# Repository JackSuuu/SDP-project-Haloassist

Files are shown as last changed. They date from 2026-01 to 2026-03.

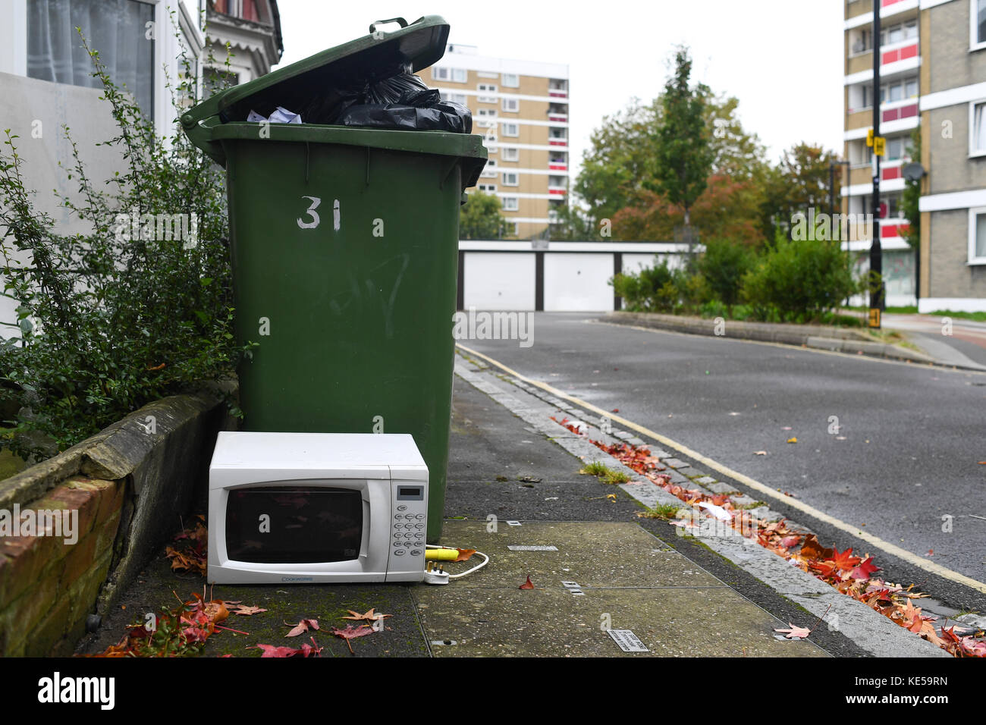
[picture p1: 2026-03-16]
perception/test_images/microwave_far.jpg

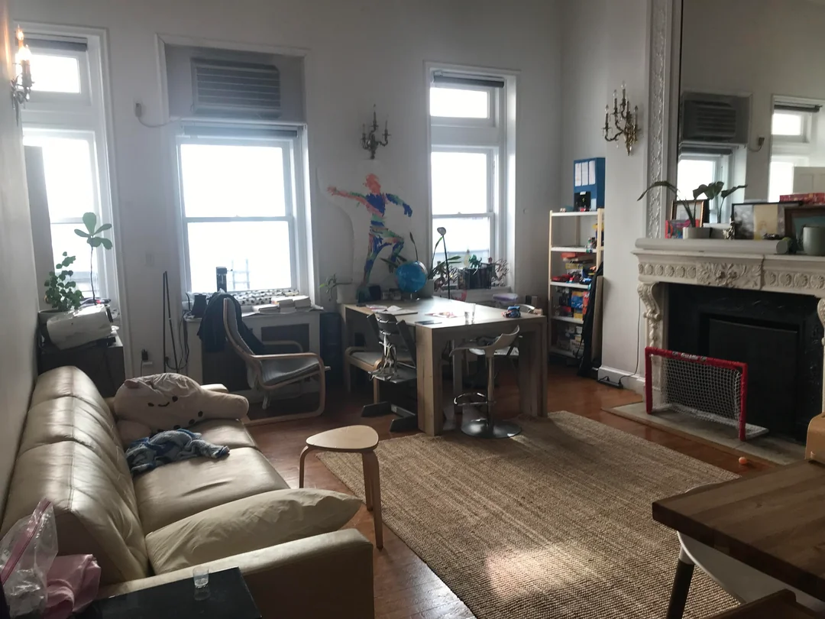
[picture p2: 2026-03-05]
test_images/test9.jpeg

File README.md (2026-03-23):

<div align="center">

# 🌟 HaloAssist

### AI-Powered Navigation Assistant for the Visually Impaired






**[Features](#-features)** • 
**[Quick Start](#-quick-start)** • 
**[Demo](#-demo)** • 
**[Architecture](#-system-architecture)** • 
**[Hardware](#-hardware-setup)** • 
**[Documentation](#-documentation)**

---

</div>

## 🎯 Overview

**HaloAssist** is an intelligent assistive technology system that helps visually impaired individuals navigate indoor environments through voice commands and haptic feedback. By combining state-of-the-art computer vision (YOLO-World) with intuitive haptic guidance, users can locate everyday objects hands-free.

### 💡 How It Works

1. **Press** → User presses a button to activate the system
2. **Speak** → User says the object they're looking for (e.g., "water bottle")
3. **Detect** → Real-time object detection using YOLO-World AI model
4. **Guide** → Directional vibration motors guide user toward the object

---

## ✨ Features

- 🗣️ **Voice-Activated Search** - Hands-free object search via speech-to-text
- 🤖 **Advanced AI Detection** - YOLO-World open-vocabulary object detection
- 📳 **Haptic Feedback** - Directional vibration guidance (2-8 motor array)
- 🎯 **Custom Object Classes** - Optimized for home and supermarket environments
- 🚀 **Multi-Platform Support** - Runs on Raspberry Pi (production) and Mac (development)
- ⚡ **Real-Time Performance** - Optimized inference for embedded systems
- 🔧 **Modular Architecture** - Clean separation of perception, hardware, and visualization

---

## 🚀 Quick Start

### Prerequisites

- Python 3.8+
- Camera (USB webcam or Raspberry Pi Camera Module)
- [Optional] Raspberry Pi 5 with GPIO peripherals

### Installation

```bash
# Clone the repository
git clone https://github.com/JackSuuu/SDP-project-Haloassist.git
cd SDP-project-Haloassist

# Create virtual environment
python3 -m venv venv
source venv/bin/activate  # On Windows: venv\Scripts\activate

# Install dependencies
cd perception
pip install -r requirements.txt
```

## Run System

```bash
cd perception/src
python main.py
```

### Run Demo

**Mac/Linux Development:**
```bash
python demo/demo_local.py
```

**Raspberry Pi (Full System):**
```bash
python demo/demo.py
```

**Image-Based Testing:**
```bash
python demo/demo_image_detector.py test_images/your_image.jpg
```

Press **`q`** to quit any demo.

---

## 🎬 Demo

### Voice Command Detection
```
User: "Find my phone"
System: 🔍 Searching for phone...
        📳 Vibrating left → Object detected at 45° left
        📳 Vibrating center → Object centered, within reach!
```

### Supported Objects
- **Home:** chair, couch, bed, door, stairs, phone, laptop, book
- **Kitchen:** refrigerator, microwave, bottle, cup, bowl, knife, fork
- **Food:** apple, banana, orange, broccoli, carrot

See [PRIORITY_OBJECTS](perception/config/hardware_config.py#L108) for the full list.

---

## 🏗️ System Architecture

```
┌─────────────────────────────────────────────────────────────┐
│                      HaloAssist System                       │
└─────────────────────────────────────────────────────────────┘

    ┌──────────────┐      ┌──────────────┐      ┌──────────────┐
    │   Hardware   │      │  Perception  │      │Visualization │
    │              │      │              │      │              │
    │ • Button     │─────▶│ • Camera     │─────▶│ • Web UI     │
    │ • Speech     │      │ • YOLO Model │      │ • Debug View │
    │ • Haptics    │◀─────│ • Detector   │      │ • Metrics    │
    └──────────────┘      └──────────────┘      └──────────────┘
```

### Project Structure

```
.
├── perception/          # Core detection system
│   ├── src/            # Source code
│   │   ├── hardware/   # Button, speech, haptic interfaces
│   │   └── perception/ # Camera and detection modules
│   ├── config/         # Hardware & model configuration
│   └── test/           # Unit tests
│
├── hardware/           # Low-level GPIO drivers
│   ├── button.py       # GPIO button control
│   ├── stt.py         # Vosk speech-to-text
│   └── yolo_haptic.py # Motor control
│
├── visualization/      # Web-based monitoring
│   ├── server.py       # Flask backend
│   └── static/         # Frontend UI
│
├── demo/              # Demo scripts
│   ├── demo.py        # Full system demo (Pi)
│   ├── demo_local.py  # Mac development demo
│   └── demo_image_detector.py  # Image testing
│
├── experiments/       # Performance benchmarks
│   └── pi5-vlm-test/ # Latency tests & results
│
└── docs/             # Documentation
    ├── QUICKSTART.md
    ├── HARDWARE_INTEGRATION.md
    └── MODEL_CONFIG.md
```

---

## 🔧 Hardware Setup

### Raspberry Pi Configuration

| Component | GPIO Pin | Description |
|---|---|---|
| Button | GPIO 5 | Activation button (pull-up, active LOW) |
| Left Motor| GPIO 22  | Left haptic feedback |
| Right Motor| GPIO 26 | Right haptic feedback |
| Camera | CSI Port | Pi Camera Module 3 |

### Supported Platforms

| Platform | Model | Image Size | FPS | Motors |
|---|---|---|-----|---|
| Raspberry Pi 3 | YOLO Nano | 160×160 | ~10 | 2 |
| Raspberry Pi 4 | YOLO Small | 320×320 | ~15 | 2 |
| Raspberry Pi 5 | YOLO Medium | 640×640 | ~30 | 2-8 |
| Mac/Linux Dev | YOLO World | 640×640 | 60+ | Simulated |

See [hardware_config.py](perception/config/hardware_config.py) for platform-specific profiles.

---

## 📚 Documentation

- **[Quick Start Guide](docs/QUICKSTART.md)** - Installation and first run
- **[Hardware Integration](docs/HARDWARE_INTEGRATION.md)** - GPIO setup and wiring
- **[Model Configuration](docs/MODEL_CONFIG.md)** - YOLO models and tuning
- **[Quick Reference](docs/QUICKREF.md)** - API and command reference

---

## 🧪 Testing

Run unit tests:
```bash
cd perception

# Test camera interface
python test/test_camera.py

# Test object detection
python test/test_detector.py

# Test haptic feedback
python test/test_haptic.py

# Test image-based detection
python test/test_image_detector.py
```

---

## ⚙️ Configuration

### Easy Platform Switching

```python
# In perception/config/hardware_config.py
apply_profile('pi5')  # Options: 'pi3', 'pi4', 'pi5', 'mac'
```

### Custom Object Detection

```python
# Add your own objects to detect
PRIORITY_OBJECTS = [
    'custom_object_1',
    'custom_object_2',
    # ... your objects here
]
```

### Adjust Haptic Feedback

```python
HAPTIC_CONFIG = {
    'default_strength': 0.5,    # Motor intensity (0.0 - 1.0)
    'default_duration': 0.25,   # Vibration duration (seconds)
    'detection_interval': 0.25, # Update frequency
}
```

---

## 🎓 Research & Benchmarks

Performance benchmarks and latency tests available in [`experiments/pi5-vlm-test/`](experiments/pi5-vlm-test/):
- YOLO detection latency measurements
- Model comparison (Nano vs Small vs Medium)
- Raspberry Pi 5 performance analysis

---

## 🤝 Contributing

Contributions are welcome! Areas for improvement:

- [ ] Expand object detection categories
- [ ] Multi-language speech support
- [ ] 8-motor haptic array implementation
- [ ] Mobile app companion
- [ ] Battery optimization for portable use

---

## 📝 License

This project is licensed under the MIT License - see the [LICENSE](LICENSE) file for details.

---

## 👥 Team

**Senior Design Project (SDP)** - Spring 2026

---

## 🙏 Acknowledgments

- [Ultralytics YOLO](https://github.com/ultralytics/ultralytics) - Object detection framework
- [Vosk](https://alphacephei.com/vosk/) - Offline speech recognition
- [Raspberry Pi Foundation](https://www.raspberrypi.org/) - Hardware platform

---

<div align="center">

**Built with ❤️ for accessibility**

[⬆ Back to Top](#-haloassist)

</div>

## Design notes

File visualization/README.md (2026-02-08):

# Motor Vibration Visualizer

A modern web-based visualization for the haptic feedback system. Shows real-time motor status with a stylized head and two vibrating motors on each side.

## Features

- 🎨 Modern dark theme with neon glow effects
- ⚡ Real-time updates via WebSocket
- 📳 Animated vibration effects when motors are active
- 🎯 Shows target object and position
- 📊 Intensity bars for each motor
- 🧪 Test buttons for manual testing

## Quick Start

```bash
# Install dependencies
pip install -r requirements.txt

# Run the server
python server.py
```

Open http://localhost:8000 in your browser.

## API Endpoints

### Update Motor State
```bash
POST /api/motor/update
Content-Type: application/json

{
    "left": true,
    "right": false,
    "intensity_left": 0.8,
    "intensity_right": 0.0,
    "target_object": "bottle",
    "position": "left"
}
```

### Detection Update (Auto-triggers motors)
```bash
POST /api/detection
Content-Type: application/json

{
    "target_object": "cup",
    "position": "right",
    "confidence": 0.85
}
```

### Quick Motor Controls
```bash
# Toggle left motor
POST /api/motor/left/true
POST /api/motor/left/false

# Toggle right motor
POST /api/motor/right/true
POST /api/motor/right/false

# Toggle both motors (center)
POST /api/motor/both/true
POST /api/motor/both/false

# Stop all motors
POST /api/motor/stop

# Get current state
GET /api/motor/state
```

### WebSocket
Connect to `/ws` for real-time motor state updates.

## Integration with Perception System

Add this to your haptic controller to send updates to the visualization:

```python
import requests

VISUALIZER_URL = "http://localhost:8000"

def send_haptic_update(left: bool, right: bool, target: str, position: str):
    """Send motor update to visualizer"""
    try:
        requests.post(f"{VISUALIZER_URL}/api/motor/update", json={
            "left": left,
            "right": right,
            "target_object": target,
            "position": position
        }, timeout=0.1)
    except:
        pass  # Don't block on visualizer errors
```

## Architecture

```
┌─────────────────────┐       WebSocket       ┌──────────────────┐
│  Perception System  │ ──────────────────────▶│   Web Browser    │
│                     │                        │                  │
│  - Object Detection │       POST /api/...    │  - Real-time UI  │
│  - Haptic Control   │ ──────────────────────▶│  - Animations    │
│  - Speech Input     │                        │  - Motor Status  │
└─────────────────────┘                        └──────────────────┘
                              │
                              ▼
                    ┌──────────────────┐
                    │   FastAPI Server │
                    │                  │
                    │  - REST API      │
                    │  - WebSocket     │
                    │  - State Mgmt    │
                    └──────────────────┘
```

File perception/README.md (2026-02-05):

# Perception Framework for Blind Assistance

An object detection framework designed to assist blind individuals in navigating home and supermarket environments using **YOLO-World** open-vocabulary detection and haptic feedback.

## Features
- **Speech-to-Text object selection** - User specifies target object via voice
- Real-time object detection using **YOLO-World** (open-vocabulary)
- **Directional haptic guidance** - Vibration indicates where object is located
- Custom object classes for home/supermarket scenarios

---

- Vibration motor array feedback (2 motors for Pi3, 8 motors for Pi5)
- Optimized for Raspberry Pi 5 / Linux
- Mac camera support for development/testing

## Workflow

1. 🔘 **Button Press** - User presses button to start
2. 🎤 **Speech Input** - User says object name ("bottle", "cup", "phone", etc.)
3. 📹 **Detection** - Camera searches for that specific object using YOLO
4. 📳 **Haptic Guidance** - Motors vibrate to indicate direction:
   - **Left**: Object on left side
   - **Right**: Object on right side
   - **Both**: Object centered
5. 🔄 **Continuous** - System keeps detecting and guiding until object found

## Project Structure
```
perception/
├── src/           # Source code
├── test/          # Test files
├── config/        # Configuration files
├── models/        # YOLO model weights
└── requirements.txt
```

## Hardware Requirements
- Raspberry Pi 5 (or Mac for development/testing)
- Camera module
- 6-8 vibration motors
- Motor driver board

## Setup
```bash
# 创建虚拟环境
python3 -m venv venv
source venv/bin/activate  # Mac/Linux
# venv\Scripts\activate  # Windows

# 安装依赖
pip install -r requirements.txt
```

## Quick Start

**Mac (Testing):**
```bash
python demo.py
```

**Raspberry Pi (Production):**
```bash
python src/main.py --no-display
```

See [QUICKSTART.md](QUICKSTART.md) for detailed instructions.

## System Architecture

```
                    ┌─────────────┐
                    │   Button    │ ──> User presses button
                    └─────────────┘
                           │
                           ↓
                    ┌─────────────┐
                    │  Speech-to- │ ──> User says "bottle"
                    │    Text     │
                    └─────────────┘
                           │
                           ↓
┌─────────────┐    ┌─────────────────────┐
│   Camera    │──> │  YOLO-World Model   │ ──> Detects "bottle" only
└─────────────┘    │ (Target: bottle)    │
                   └─────────────────────┘
                           │
                           ↓
                   ┌─────────────────┐
                   │ Object Located? │
                   └─────────────────┘
                     │            │
                    Yes          No
                     │            │
                     ↓            ↓
              ┌──────────┐   Keep searching
              │ Position │
              │ Analysis │
              └──────────┘
                     │
                     ↓
         ┌──────────────────────┐
         │ Haptic Controller    │
         │ - Left motor (L)     │
         │ - Right motor (R)    │
         └──────────────────────┘
                     │
                     ↓
         [Directional Guidance]
         L: Left object
         R: Right object
         L+R: Center object
```

## Core Modules

- **detector.py**: YOLO-World based object detection with custom classes
- **haptic.py**: Vibration motor control for directional guidance  
- **camera.py**: Cross-platform camera interface (Mac/RPi)
- **main.py**: Main integration and control loop

## Why YOLO-World?

- **Open-vocabulary detection**: Detect custom object categories without retraining
- **Flexible**: Easily add new object classes for different scenarios
- **Accurate**: Better performance for specific home/supermarket items
- **Efficient**: Real-time performance on Raspberry Pi 5

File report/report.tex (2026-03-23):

%% Template for SDP report, adapted from mlp_cw2_template, 2018. 

%% Based on  LaTeX template for ICML 2017 - example_paper.tex at 
%%  https://2017.icml.cc/Conferences/2017/StyleAuthorInstructions

\documentclass{article}
\input{mlp2018_includes}
\usepackage{fancyvrb}

%% You probably do not need to change anything above this comment

%% REPLACE the details in the following commands with your details
\setGroupNumber{7}
\setGroupName{Halo}
\setProductName{Halo Assist}
\setDemoNumber{3}
\setLogoFileName{figs/logo.png}

\begin{document} 

\makeSDPTitle{Demo}

\begin{abstract} 
HaloAssist is a wearable haptic guidance system intended to provide object-search assistance and spatial awareness for partially sighted users through real-time vibrotactile feedback.

In Demo 3, the system was consolidated into a complete end-to-end pipeline. The implementation replaces discrete motor triggering with continuous offset-based haptic mapping, integrates local offline speech transcription via Vosk~\cite{alphacep_vosk}, introduces lightweight LLM-based noun extraction from natural-language commands~\cite{gerganov2023llama}, and applies YOLO-World~\cite{cheng2024yoloworld} for open-vocabulary target detection.
\end{abstract}

\section{Project Management Update} 

\subsection{Project Goals}

The primary objective of this demo was to deliver a reliable end-to-end assistive workflow in which a user issues a natural spoken command and receives continuous directional haptic guidance toward a detected target object.

Table~\ref{tab:progress} summarizes progress against the specific objectives.

\begin{table*}[t]
\centering
\setlength{\tabcolsep}{4pt}
\renewcommand{\arraystretch}{1.3}
\begin{tabular}{|p{0.18\textwidth}|p{0.74\textwidth}|}
\hline
\textbf{Status} & \textbf{Objective} \\
\hline
Achieved & 
\begin{minipage}[t]{\linewidth}
\begin{itemize}
    \item Implementing continuous offset-based haptic feedback for precise directional guidance
    \item Integrating local offline Speech-to-Text (STT) parsing with Vosk and an LLM for robust target noun extraction
    \item Utilizing YOLO-World for dynamic, open-vocabulary object detection based on voice commands
    \item Calculating the object's spatial offset relative to the camera to direct the motor intensity
\end{itemize}
\end{minipage} \\
\hline
Partially Achieved & 
\begin{minipage}[t]{\linewidth}
\begin{itemize}
    \item Miniaturizing hardware components into the final 3D-printed CAD enclosure
    \item End-to-end latency optimization for real-time responsiveness on the Raspberry Pi 5~\cite{rpi5}
    \item Expanding to a full 8-motor haptic array setup
\end{itemize}
\end{minipage} \\
\hline
\end{tabular}
\caption{Progress Overview}
\label{tab:progress}

\vspace{3mm}
\refstepcounter{table}\label{tab:team}
\textbf{Table \thetable.} Team Contributions and Responsibilities
\vspace{2mm}

\begin{tabular}{|p{0.16\textwidth}|p{0.18\textwidth}|p{0.08\textwidth}|p{0.50\textwidth}|}
\hline
\textbf{Team} & \textbf{Member} & \textbf{Hours} & \textbf{Role/Contribution} \\
\hline
Hardware & Member 1 & 40 & Led the hardware team in integrating the I2C MUX + DRV2605 and continued 3D modelling the system enclosure. \\
\hline
Perception & Member 2 & 42 & Integrated YOLO-World dynamic class updating and optimised standard YOLO pipeline for inference on the Pi. \\
\hline
Haptics & Member 3 & 38 & Developed and verified the continuous offset motor mapping, dead zone logic, and motor pulse interval behaviour. \\
\hline
Software & Member 4 & 35 & Implemented the local Vosk STT pipeline, integrated the LLM noun extraction, and managed the main system state logic handling button interrupts. \\
\hline
\end{tabular}
\end{table*}

\subsection{Deviations from Intended Goals}

\textbf{Hardware packaging:} CAD and enclosure iterations progressed substantially; however, full miniaturization remains incomplete due to repeated integration dependencies among camera placement, cable routing, and haptic-driver mounting.

\textbf{Latency tuning:} The perception loop is functionally stable, but end-to-end latency remains under optimization to maintain consistent performance on Raspberry Pi 5 across varying illumination and object classes.

\textbf{NLP pipeline design:} The initial direct-label parsing approach was replaced by a two-stage pipeline in which Vosk transcribes full utterances and a fine-tuned LLM extracts the target noun phrase. This change improved robustness for natural commands such as ``find my water bottle''.

\subsection{Team and System Organization}

HaloAssist is an end-to-end assistive system composed of tightly integrated hardware and software components. The workflow couples a physical trigger interface, speech capture, natural-language target extraction, vision-based localization, and continuous directional haptic output. During this demo cycle, development focused on maturing each subsystem while preserving full-pipeline operability for repeated evaluations.

From earlier demonstrations to the current version, four tracks were advanced in parallel: (i) hardware reliability and enclosure iteration, (ii) perception and model integration, (iii) continuous haptic control logic, and (iv) orchestration tooling for reproducible execution. The resulting architecture supports command-driven object search by extracting a target noun phrase from speech, applying target-specific YOLO-World detection, and mapping visual offset to continuous motor intensity.

In addition, a visualizer website was developed to support both debugging and demonstration (refer to Appendix C, Figure~\ref{fig:website} for the user interface). This interface exposes detections, system states, and runtime behavior during integration tests, thereby reducing diagnosis time for cross-module issues.

To maximize efficiency and collaboration within the team, we used the following working practices:
\begin{itemize}
    \item \textbf{Task tracking and ownership:} We maintained feature ownership by subsystem (Hardware, Perception, Haptics, Software) and used GitHub~\cite{github} issue/task tracking to prioritize integration-critical work. To ensure structural oversight across these tracks, a centralized timeline was established and maintained via Google Docs (see Appendix B, Figure~\ref{fig:timeline}).
    \item \textbf{Regular coordination:} We conducted weekly sync meetings and short checkpoint updates before integration milestones to surface blockers early.
    \item \textbf{Code integration discipline:} We used branch-based development with pull requests and peer review before merging to reduce regression risk in the main loop.
    \item \textbf{Bash-based reproducibility:} We used Bash scripts for repeatable setup and experiment execution across machines (development and Raspberry Pi) to keep runs consistent and reduce manual configuration errors.
    \item \textbf{Verification-driven iteration:} We validated changes with dedicated scripts for camera, detection, speech, latency, and haptic mapping, then iterated parameters based on measured output.
    \item \textbf{Platform profile consistency:} We used profile-based configuration (Pi3, Pi4, Pi5, Mac) so the same codebase can be tested locally and deployed to target hardware with minimal changes.
\end{itemize}

In the next phase, the same organizational model will be retained for final-stage optimization, with emphasis on end-to-end latency reduction, improved ergonomics, and expanded command coverage while preserving guidance stability.

\subsection{Team Workload}

The current workload allocation and ownership structure are summarized in Table~\ref{tab:team}. Values remain provisional and will be finalized in the final submission.

\subsection{Budget Summary}

Current prototype expenditure is primarily driven by compute hardware and haptics electronics. Cost reduction in the next iteration is expected through enclosure consolidation, wiring simplification, and bulk procurement of repeated components.

\section{Quantitative Analysis and Testing}

The evaluation protocol was strictly designed to assess the core functionalities of the HaloAssist pipeline. The primary areas of investigation include (i) the reliability and precision of continuous haptic guidance, (ii) the responsiveness and end-to-end latency of the speech-to-detection loop processing, and (iii) the practical system behavior and stability under realistic operational conditions. 

To ensure the system meets the requirements for real-time assistive applications, quantitative metrics were gathered across varying environmental conditions and interaction patterns. This section details the testing methodologies and presents the empirical results obtained from subsystem validation.

\subsection{Continuous Haptic Mapping Tests}

The continuous offset mapping implementation, utilizing an I2C multiplexer~\cite{nxp_i2c} and DRV2605 haptic motor drivers~\cite{ti_drv2605} in real-time playback mode, was systematically evaluated across the full horizontal camera field of view. The goal was to quantify the smoothness and interpretability of the directional feedback.

\begin{itemize}
    \item \textbf{Relevance:} The accuracy of continuous offset estimation, the stability of pulse-interval behavior, and the strict enforcement of dead-zone boundaries were assessed. These metrics are critical to ensure that the directional feedback provided to the user is both precise and unambiguously interpretable without causing sensory overload.
    \item \textbf{Interpretation:} Experimental data confirmed that the mapping successfully produced a smooth, continuous strength gradient ranging from -1.0 (far left) to +1.0 (far right). To prevent distracting vibrations when the target is centered, a dead zone of $\pm 12\%$ relative to the frame center was implemented, which effectively suppressed center-region noise and flickering. Furthermore, the motor pulse intervals correctly varied from $0.45\text{\,s}$ (slow) to $0.55\text{\,s}$ (fast) in direct correlation with the computed feedback intensity.
    \item \textbf{Robustness:} A rigorous automated sweep over 21 distinct horizontal positions within a 1280px resolution frame was performed to identify any non-linearities or signal discontinuities. Using a predefined jump threshold of $< 0.3$ to flag irregular motor actuation, zero abrupt transitions were observed across all test instances. This indicates a highly stable and predictable linear scaling behavior across the entire visual field.
\end{itemize}

\begin{table}[h]
\centering
\small
\setlength{\tabcolsep}{3pt}
\renewcommand{\arraystretch}{1.2}
\begin{tabular}{p{0.28\columnwidth}p{0.22\columnwidth}p{0.26\columnwidth}p{0.12\columnwidth}}
\hline
\textbf{Test Category} & \textbf{Metric / Objective} & \textbf{Range / Result} & \textbf{Status} \\
\hline
Continuous Offset mapping & Jump threshold $< 0.3$ & Smooth gradient from -1.0 to 1.0 & $\surd$ PASS \\
Pulse Interval Behavior & Fast/Slow mapping & 1.82 to 2.22 pulses/sec & $\surd$ PASS \\
Dead Zone Stability & Prevent center flickering & $\pm$ 12\% (152px width) inactive & $\surd$ PASS \\
\hline
\end{tabular}
\caption{Continuous Motor Mapping Test Results}
\label{tab:haptic-tests}
\end{table}

\subsection{Speech and Detection Pipeline Timing}

This subsystem was comprehensively tested to verify low operational latency. Table~\ref{tab:pipeline-latency} logs the detailed breakdown components of the interaction loop under simulated use conditions.

\begin{figure}[h]
    \centering
    % \includegraphics[width=0.8\linewidth]{figs/latency_plot.png}
    \vspace{2cm} % Placeholder space
    \caption{Latency distribution breakdown showing primary processing bottlenecks vs. system target limits.}
    \label{fig:latency-distribution}
\end{figure}

The latency data indicate that the system architecture meets operational benchmarks, yet isolated processing spikes during LLM NLP extraction and YOLO-World edge deployment remain targets for optimization. These measurements emphasize the ongoing challenges of real-time multi-modal inference on embedded platforms like the Raspberry Pi 5.

\begin{table}[h]
\centering
\small
\setlength{\tabcolsep}{3pt}
\renewcommand{\arraystretch}{1.2}
\begin{tabular}{p{0.36\columnwidth}p{0.30\columnwidth}p{0.22\columnwidth}}
\hline
\textbf{Pipeline Step} & \textbf{Current (ms)} & \textbf{Target (ms)} \\
\hline
Button press to listen start & 120 & 100 \\
Vosk transcription & 380 & 300 \\
LLM noun extraction (llama.cpp) & 95 & 70 \\
YOLO-World first valid detection & 210 & 160 \\
Haptic update command issue & 45 & 30 \\
End-to-end command to guidance & 850 & 650 \\
\hline
\end{tabular}
\caption{Speech-to-guidance latency breakdown (draft values).}
\label{tab:pipeline-latency}
\end{table}

\section{Budget}
Table~\ref{tab:budget-current} provides a draft cost breakdown for the current prototype build. These values are provisional and will be replaced with exact purchase totals in the final version.

\begin{table}[h]
\centering
\small
\setlength{\tabcolsep}{3pt}
\renewcommand{\arraystretch}{1.2}
\begin{tabular}{p{0.42\columnwidth}p{0.20\columnwidth}p{0.22\columnwidth}}
\hline
\textbf{Item} & \textbf{Qty} & \textbf{Cost (\pounds)} \\
\hline
Raspberry Pi 5 + storage + power & 1 & 115 \\
Camera module and mounting & 1 & 35 \\
DRV2605 drivers + I2C multiplexer & 1 set & 28 \\
Haptic motors and wiring materials & 1 set & 32 \\
3D printing materials and enclosure parts & 1 set & 40 \\
Auxiliary electronics and connectors & 1 set & 20 \\
\hline
\textbf{Total (draft)} &  & \textbf{270} \\
\hline
\end{tabular}
\caption{Current prototype budget breakdown (draft values).}
\label{tab:budget-current}
\end{table}

In the next revision, cost will be reduced through compact enclosure redesign and consolidation of repeated electronics purchases.

\section{Miscellaneous}
\label{sec:misc}

This section details several components crucial to the overall efficacy, usability, and architecture of the HaloAssist project. This includes insights drawn from human-computer interaction studies, diagnostic tools built to facilitate development, software architectural decisions, integration of applied Natural Language Processing pipelines, and the underpinning mathematical models controlling real-time spatial haptic interpretation.

\subsection{User Study and Feedback Mechanisms}

Iterative user-facing trials conducted throughout the integration phase formed the core feedback loop for system refinement. The testing protocol was primarily designed to evaluate the intuitive phrasing required for voice commands, the ergonomic comfort and physical weight load of the wearable components, and the cognitive clarity of continuous haptic guidance mechanisms.

Study participants were explicitly instructed to utilize natural, grammatically unstructured voice commands—simulating real-world scenarios rather than strict label matching strategies. While following the generated haptic cues to align their orientation with physical target objects, qualitative feedback and navigation errors were logged.

The most critical findings synthesized from the study were:
\begin{itemize}
    \item Participants exhibited a strong preference for complex, sentence-style commands over rigid keyword interactions, necessitating the adoption of a sophisticated noun-extraction mechanism within the NLP loop.
    \item Qualitative feedback indicated that the continuous modulation of haptic intensity was cognitively easier to interpret and trace than traditional binary left/right discrete vibration bursts. The continuous approach allowed users to estimate radial distance more accurately.
    \item Ergonomic observations underscored that wearability, thermal management of the Raspberry Pi 5 under load, and precise mounting comfort remain primary constraints preventing extended operational sessions. Current prototype weight distribution specifically impacts long-term wearability.
\end{itemize}

These empirical observations heavily influenced the subsequent architectural restructuring and prioritized parameters for system configuration tuning, emphasizing computational offloading where possible to simplify embedded load on the Raspberry Pi 5~\cite{rpi5}.

\subsection{Diagnostic Observability Interface}

To alleviate iterative testing friction, a lightweight, dedicated Web-based observability portal was developed and integrated locally into the pipeline to streamline monitoring processes. This architecture allowed real-time telemetry inspection inside the unified feedback loop, operating as an essential diagnostic layer during demonstrations and field testing.

The functional scope of the visualizer interface encompasses:
\begin{itemize}
    \item Rendering live camera frames overlaid with YOLO-World detection bounding boxes and confidence scores.
    \item Publishing real-time systemic state transitions (e.g., transitions between `listening`, `transcribing`, `extracting targets`, `visual scanning`, and `haptic actuation`). 
    \item Displaying live inference timing data and target spatial confidence signals to aid root-cause diagnosis of latency or localization variations.
\end{itemize}

The deployment of this diagnostic mechanism drastically reduced overall debugging turnaround time and vastly enhanced the coordination capabilities across the perception, haptic, and hardware teams during end-to-end integration stress tests.

\subsection{Systemic Subsystem Architecture}

HaloAssist utilizes a tightly coupled, closed-loop assistive computational architecture to facilitate sequential information processing:
\begin{enumerate}
    \item A mechanical hardware interrupt (button press) asynchronously triggers the command listening phase.
    \item A localized, offline implementation of Vosk STT~\cite{alphacep_vosk} transcribes the raw captured audio into unstructured text strings.
    \item A locally-hosted Large Language Model (LLM), optimized specifically for low-latency edge inference, parses the transcription to extract the highest-probability semantic target noun or noun phrase.
    \item The extracted target is piped as dynamic class label input into the YOLO-World~\cite{cheng2024yoloworld} object detection model via inference node queries.
    \item Based on the visual bounding box coordinates generated, the software calculates an offset value. This spatial target position is transformed mathematically and output directly to the I2C-driven continuous haptic motor array.
\end{enumerate}

By localizing all processing logic and model configurations to the hardware itself, the architecture mitigates latency vulnerabilities previously presented by network dependence, rendering the device fully standalone.

\subsection{NLP Integration using LLM and Llama.cpp}

Historically, matching noisy and unstructured Speech-to-Text outputs natively to localized fixed class labels manifested critical inaccuracies. To correct this, a fine-tuned Large Language Model acting as a semantic parser replaced naive string-matching algorithms. This shift vastly improved system tolerance and accuracy when handling natural human colloquialisms, complex phrasing, embedded filler words, and subjective adjectival modifiers.

Given the rigid compute and memory constraints imposed by the Raspberry Pi 5 platform, achieving viable inference rates required integration of \texttt{llama.cpp}~\cite{gerganov2023llama}. The \texttt{llama.cpp} execution framework optimizes hardware acceleration and mitigates the otherwise unacceptable parsing overhead typical of transformer architectures while fully preserving linguistic target-extraction fidelity.

\subsection{Continuous Haptic Control Mapping}

The implemented mapping in the haptic controller is continuous and position-dependent.

For object center $x_t$, frame center $x_c$, and frame width $W$:
\[
o = \text{clip}\left(\frac{x_t - x_c}{W/2}, -1, 1\right), \quad m = |o|
\]

If the object is near center ($m < b$, where $b$ is the center band), both motors provide a soft cue:
\[
I_L = I_R = I_c
\]

Otherwise, dominant intensity is:
\[
I_d = m^{\gamma} \cdot I_{\max}, \quad I_s = r \cdot I_d
\]
where $\gamma$ is the shaping parameter and $r$ is the support ratio.

Direction assignment:
\[
\text{if } o < 0: (I_L, I_R) = (I_d, I_s), \qquad
\text{else}: (I_L, I_R) = (I_s, I_d)
\]

Each motor is updated continuously in real-time playback mode using an 8-bit command value:
\[
v = \lfloor \text{clip}(I, 0, 1) \cdot 127 \rfloor
\]

This produces smooth vibration transitions as the target moves across the frame, avoiding abrupt switching and improving directional guidance clarity.

\subsection{Next Steps and Iterative Refinement}

Empirical feedback gathered directly from qualitative responses asserts definitively that the continuous gradient haptic mapping algorithms exhibit vastly superior interpretative thresholds compared to original distinct pulse mapping modes. In moving toward finalization, the subsequent iteration phases aim to consolidate hardware footprint for superior wearable ergonomics, refine model quantization to aggressively limit structural end-to-end latency, and expand vocabulary mapping accuracy. The ultimate goal is delivering a comprehensively safe, predictable, and fully embedded multi-modal navigation system.
 
\clearpage
\appendix
\section{Appendix}

\subsection{Appendix A: Template Inclusions}

% NOTE: The following bubble sort example is retained strictly to fulfill the original template and assignment guidelines requiring theoretical computational algorithmic representation.

\begin{algorithm}[h]
   \caption{Bubble Sort}
   \label{alg:example}
\begin{algorithmic}
   \STATE {\bfseries Input:} data $x_i$, size $m$
   \REPEAT
   \STATE Initialize $noChange = true$.
   \FOR{$i=1$ {\bfseries to} $m-1$}
   \IF{$x_i > x_{i+1}$}
   \STATE Swap $x_i$ and $x_{i+1}$
   \STATE $noChange = false$
   \ENDIF
   \ENDFOR
   \UNTIL{$noChange$ is $true$}
\end{algorithmic}
\end{algorithm}

\subsection{Appendix B: Project Timeline and Task Management}

Figure~\ref{fig:timeline} illustrates the master timeline and milestone tracking documentation maintained via Google Docs. This shared tracking framework ensured synchronous cross-team development and effectively aligned both hardware and software delivery schedules. 

\begin{figure*}[h]
    \centering
    
    \caption{Project timeline and task distribution maintained via Google Docs.}
    \label{fig:timeline}
\end{figure*}

\subsection{Appendix C: System Visualizer Interface}

Figure~\ref{fig:website} displays the lightweight web-based observability interface built to debug the live inference loop. The visualizer streams the on-device camera feed, YOLO-World detection bounding boxes, and internal system state transitions to assist in rapidly diagnosing latency and localization deviations.

\begin{figure*}[h]
    \centering
    
    \caption{The diagnostic observability interface capturing live camera feeds and detection confidence.}
    \label{fig:website}
\end{figure*}

\clearpage
\onecolumn
\bibliography{example-ref}

\end{document}

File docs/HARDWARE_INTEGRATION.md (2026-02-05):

# Hardware Integration Guide

## Overview

The perception system has been refactored to cleanly integrate with the hardware modules from the `hardware/` directory. All hardware-specific functionality is now properly abstracted through clean interfaces.

## Architecture

```
perception/src/
├── hardware/              # Hardware interface modules (NEW)
│   ├── __init__.py       # Exports ButtonInterface, SpeechInterface, HapticController
│   ├── button_interface.py
│   ├── speech_interface.py
│   └── haptic_controller.py
├── perception/
│   ├── camera.py         # Camera interface (Mac + Pi support)
│   ├── detector.py       # YOLO-World object detection
│   └── __init__.py
└── main.py              # Main application

hardware/                 # Original Pi hardware modules
├── button.py            # GPIO button control (used as reference)
├── stt.py              # Vosk speech-to-text (imported by speech_interface)
└── yolo_haptic.py      # Motor control logic (used as reference)
```

## Hardware Modules

### 1. ButtonInterface (`hardware/button_interface.py`)
- Handles GPIO button input
- Auto-detects Raspberry Pi
- Falls back to disabled mode on non-Pi systems
- **GPIO Pin:** 5 (BCM mode, active LOW)

### 2. SpeechInterface (`hardware/speech_interface.py`)
- Wraps Vosk speech-to-text functionality
- Uses `hardware/stt.py` module
- Returns recognized text from voice input
- **Model path:** `/home/pi/vosk-model/vosk-model-small-en-us-0.15`

### 3. HapticController (`hardware/haptic_controller.py`)
- Controls 2 vibration motors (left/right)
- Provides directional guidance based on object position
- Uses PWM for motor intensity control
- **GPIO Pins:** 22 (left), 26 (right)

### 4. CameraInterface (`perception/camera.py`)
- Supports both Mac (OpenCV) and Pi (picamera2)
- Auto-detects platform and uses appropriate camera backend
- Graceful fallback to OpenCV if picamera2 unavailable

## Usage

### Basic Usage (Mac - Testing)
```bash
cd perception
python src/main.py
```

### Raspberry Pi (Production)
```bash
cd perception
python src/main.py --no-display --enable-speech
```

### Command-line Options
- `--model MODEL_PATH`: Path to YOLO-World model (default: yolov8s-world.pt)
- `--no-display`: Disable visual display (for headless Pi)
- `--enable-speech`: Enable speech input via button press

## Hardware Setup on Raspberry Pi

### GPIO Pin Configuration
| Component | GPIO Pin (BCM) | Description |
|---|---|---|
| Button | 5 | Input, pull-up, active LOW |
| Left Motor | 22 | PWM output |
| Right Motor | 26 | PWM output |

### Wiring Diagram
```
Button:     GPIO 5 ----[Button]---- GND

Motors:     GPIO 22 ----[Driver]----[Left Motor]
            GPIO 26 ----[Driver]----[Right Motor]
```

## Dependencies

### Core Dependencies (requirements.txt)
```
ultralytics
opencv-python
numpy
```

### Raspberry Pi Only
```
RPi.GPIO          # For button input
gpiozero          # For motor control
picamera2         # For camera
sounddevice       # For audio capture
vosk              # For speech recognition
```

## Platform Detection

All hardware modules include automatic platform detection:

```python
def _check_raspberry_pi(self) -> bool:
    """Check if running on Raspberry Pi"""
    try:
        with open('/proc/device-tree/model', 'r') as f:
            model = f.read()
            return 'raspberry pi' in model.lower()
    except:
        return False
```

- **On Raspberry Pi:** Full hardware functionality enabled
- **On Mac/Other:** Simulated/disabled mode for testing

## Code Quality Features

### Clean Abstractions
- All hardware access is through well-defined interfaces
- No direct GPIO/hardware calls in main application code
- Easy to mock for testing

### Error Handling
- Graceful degradation when hardware unavailable
- Clear error messages and warnings
- No crashes on missing hardware

### Cross-Platform Support
- Single codebase works on Mac (development) and Pi (production)
- Automatic platform detection
- Appropriate backend selection

## Integration Flow

```
main.py
  ├─> ObjectDetector (YOLO-World)
  │     └─> detect objects
  │
  ├─> CameraInterface
  │     ├─> [Mac] OpenCV
  │     └─> [Pi] picamera2
  │
  ├─> HapticController
  │     └─> guide_to_target() ──> vibration motors
  │
  ├─> ButtonInterface
  │     └─> is_pressed() ──> GPIO button
  │
  └─> SpeechInterface
        └─> listen() ──> hardware/stt.py ──> Vosk
```

## Future Enhancements

1. **Dynamic Class Selection**: Use speech input to change detection classes on-the-fly
2. **Multi-motor Arrays**: Expand from 2 to 6-8 motors for finer directional guidance
3. **Audio Feedback**: Add TTS for object announcements
4. **Configuration File**: Move GPIO pins and settings to config file

## Troubleshooting

### Button not responding
- Check GPIO wiring (pin 5 to button, button to GND)
- Verify pull-up resistor configuration
- Check `/proc/device-tree/model` for Pi detection

### Motors not vibrating
- Verify GPIO pins 22 and 26 are connected
- Check motor driver power supply
- Test with manual GPIO control

### Camera not working
- **Pi:** Install picamera2: `sudo apt install python3-picamera2`
- **Mac:** Ensure camera permissions granted
- Check camera device index (default: 0)

### Speech recognition issues
- Verify Vosk model at `/home/pi/vosk-model/vosk-model-small-en-us-0.15`
- Check microphone connection
- Test with button press

## Testing Without Hardware

The system gracefully handles missing hardware:

```bash
# On Mac - everything simulated
python src/main.py

# Output shows:
# - Haptic feedback: simulated
# - Button input: disabled  
# - Speech input: disabled
```

## Contributing

When adding new hardware modules:
1. Create interface in `perception/src/hardware/`
2. Include platform detection
3. Implement graceful fallback
4. Add to `hardware/__init__.py`
5. Update this documentation

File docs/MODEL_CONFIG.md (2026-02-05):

# Model and Hardware Configuration Guide

## Quick Start

### Choose Your Model

The system now supports multiple YOLO models for different hardware capabilities:

```bash
# Pi3 (tested) - Fast, lightweight
python src/main.py --model nano --no-display

# Pi4 - Balanced
python src/main.py --model small --no-display

# Pi5 (future) - Best accuracy, 8-motor support
python src/main.py --model medium --no-display

# Mac/Testing - Full YOLO-World features
python src/main.py --model world-small
```

### Platform Profiles

Use pre-configured profiles for optimal performance:

```bash
# Pi3 profile (nano model, 160px, 2 motors)
python src/main.py --profile pi3 --no-display

# Pi5 profile (medium model, 640px, 8 motors)
python src/main.py --profile pi5 --no-display

# Mac profile (for development)
python src/main.py --profile mac
```

## Configuration System

All hardware and model settings are centralized in [`config/hardware_config.py`](config/hardware_config.py).

### Available Models

| Model Name | File | Speed | Accuracy | Best For |
|---|---|---|---|---|
| `nano` | yolov8n.pt | ⚡⚡⚡ | ⭐⭐ | Pi3 |
| `small` | yolov8s.pt | ⚡⚡ | ⭐⭐⭐ | Pi4 |
| `medium` | yolov8m.pt | ⚡ | ⭐⭐⭐⭐ | Pi5 |
| `world-small` | yolov8s-world.pt | ⚡⚡ | ⭐⭐⭐ | Mac/Custom classes |
| `world-medium` | yolov8m-world.pt | ⚡ | ⭐⭐⭐⭐ | Pi5/Custom classes |

### Motor Configurations

#### 2-Motor Array (Current - Pi3/Pi4)
```
        Front
          ↑
    Left ← → Right
```

**GPIO Pins:**
- Left motor: GPIO 22
- Right motor: GPIO 26

**Directions:**
- Left third of frame: Left motor vibrates
- Right third: Right motor vibrates
- Center third: Both motors vibrate

#### 8-Motor Array (Future - Pi5)
```
          Front
        Front-Right
    Right      Left
Back-Right    Front-Left
          Back-Left
```

**GPIO Pins:**
- Front: GPIO 17
- Front-right: GPIO 18
- Right: GPIO 22
- Back-right: GPIO 23
- Back: GPIO 24
- Back-left: GPIO 25
- Left: GPIO 26
- Front-left: GPIO 27

**Directions:** 360° directional guidance based on object angle

## Upgrading to Pi5 + 8 Motors

### Step 1: Update Hardware Configuration

Edit [`config/hardware_config.py`](config/hardware_config.py):

```python
# Change the active motor configuration
MOTOR_PINS = MOTOR_PINS_8  # Was: MOTOR_PINS_2

# Change the default model
DEFAULT_MODEL = 'medium'  # Was: 'world-small'

# Adjust YOLO settings for Pi5
YOLO_CONFIG = {
    'conf_threshold': 0.25,
    'imgsz': 640,  # Was: 160 for Pi3
    'verbose': False,
}

# Adjust camera settings for Pi5
CAMERA_CONFIG = {
    'width': 1280,  # Was: 640
    'height': 720,  # Was: 480
    'fps': 30,
}
```

### Step 2: Wire 8 Motors

Connect motors to the GPIO pins as specified in `MOTOR_PINS_8`.

### Step 3: Run with Pi5 Profile

```bash
python src/main.py --profile pi5 --no-display
```

That's it! The system automatically adapts to 8-motor configuration.

## Custom Configuration

### Using Custom Model File

```bash
# Use your own YOLO model file
python src/main.py --model /path/to/custom_model.pt
```

### Modifying Detection Classes

Edit [`config/hardware_config.py`](config/hardware_config.py):

```python
PRIORITY_OBJECTS = [
    'person', 'chair', 'table',  # Add/remove objects
    'bottle', 'cup', 'phone',
    # Add your custom objects for YOLO-World
]
```

### Adjusting Motor Pins

Edit [`config/hardware_config.py`](config/hardware_config.py):

```python
# Custom 2-motor setup
MOTOR_PINS_2 = {
    'left': 17,   # Change pins as needed
    'right': 18,
}

# Custom 8-motor setup
MOTOR_PINS_8 = {
    'front': 5,
    'front_right': 6,
    # ... etc
}
```

### Tuning Haptic Feedback

Edit [`config/hardware_config.py`](config/hardware_config.py):

```python
HAPTIC_CONFIG = {
    'default_strength': 0.7,    # Increase motor intensity (0.0-1.0)
    'default_duration': 0.3,    # Longer vibration (seconds)
    'detection_interval': 0.1,  # More frequent updates
}
```

## Platform Comparison

| Feature | Pi3 | Pi4 | Pi5 |
|---|-----|-----|-----|
| Model | yolov8n | yolov8s | yolov8m |
| Image Size | 160px | 320px | 640px |
| FPS (est.) | 10-15 | 20-25 | 30+ |
| Motors | 2 | 2 | 8 |
| Camera | 640x480 | 640x480 | 1280x720 |
| Detection Quality | ⭐⭐ | ⭐⭐⭐ | ⭐⭐⭐⭐ |

## Examples

### Mac Development
```bash
# Use YOLO-World for testing with display
python src/main.py --model world-small
```

### Pi3 Production (Current)
```bash
# Tested configuration with nano model
python src/main.py --profile pi3 --no-display
```

### Pi5 Production (Future)
```bash
# Full 8-motor array with best model
python src/main.py --profile pi5 --no-display --enable-speech
```

### Custom Setup
```bash
# Custom model with speech
python src/main.py --model /path/to/model.pt --enable-speech
```

## Code Structure

```
perception/
├── config/
│   ├── hardware_config.py     # ⭐ Main configuration file
│   └── settings.py
├── src/
│   ├── hardware/
│   │   ├── haptic_controller.py   # Supports 2-8 motors automatically
│   │   ├── button_interface.py
│   │   └── speech_interface.py
│   ├── perception/
│   │   ├── detector.py            # Supports all YOLO models
│   │   └── camera.py
│   └── main.py                    # Model selection + profiles
└── requirements.txt
```

## Extending the System

### Adding a New Motor Array Size

1. Define pin mapping in `hardware_config.py`:
```python
MOTOR_PINS_16 = {
    'n': 17, 'nne': 18, 'ne': 22, 'ene': 23,
    'e': 24, 'ese': 25, 'se': 26, 'sse': 27,
    # ... continue pattern
}
```

2. Update `guide_to_target()` in `haptic_controller.py` to handle new configuration.

### Adding a New Model

1. Add to `YOLO_MODELS` in `hardware_config.py`:
```python
YOLO_MODELS = {
    # ... existing models
    'large': 'yolov8l.pt',
    'world-large': 'yolov8l-world.pt',
}
```

2. Use it:
```bash
python src/main.py --model large
```

### Creating a New Platform Profile

Add to `get_profile()` in `hardware_config.py`:

```python
profiles = {
    # ... existing profiles
    'jetson': {
        'model': 'medium',
        'imgsz': 640,
        'camera_width': 1920,
        'camera_height': 1080,
        'motor_pins': MOTOR_PINS_8,
    },
}
```

Use it:
```bash
python src/main.py --profile jetson
```

## Troubleshooting

### Model file not found
- Ensure model file is in the perception directory or provide full path
- Download models: `yolo export model=yolov8n.pt format=pt`

### Wrong number of motors detected
- Check `MOTOR_PINS` in `hardware_config.py`
- Verify GPIO wiring matches configuration

### Performance issues
- Use smaller `imgsz` (160, 320 instead of 640)
- Use faster model ('nano' instead of 'medium')
- Apply appropriate platform profile

## Summary

✅ **Easy model switching**: Just use `--model` flag  
✅ **Platform profiles**: Pre-configured for Pi3/Pi4/Pi5  
✅ **Extensible**: Add motors/models/platforms in config file  
✅ **No code changes needed**: All settings in `hardware_config.py`  
✅ **Future-proof**: Ready for Pi5 and 8-motor upgrade

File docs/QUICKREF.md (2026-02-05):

# Quick Reference - Perception System

## Current Setup (Pi3)

```bash
cd perception
python src/main.py --profile pi3 --no-display
```

**Model:** yolov8n.pt (tested ✅)  
**Motors:** 2 (left/right on GPIO 22, 26)  
**Camera:** 640x480 via picamera2

## Command Options

### Model Selection
```bash
# Use predefined model
--model nano          # yolov8n.pt (current/Pi3)
--model small         # yolov8s.pt
--model medium        # yolov8m.pt (Pi5)
--model world-small   # yolov8s-world.pt (Mac)

# Use custom model file
--model /path/to/custom.pt
```

### Platform Profiles
```bash
--profile pi3    # Optimized for Pi3 (current)
--profile pi4    # Optimized for Pi4
--profile pi5    # Optimized for Pi5 (future)
--profile mac    # Mac development
```

### Display & Input
```bash
--no-display       # Headless mode (for Pi)
--enable-speech    # Enable voice input via button
```

## Common Usage Patterns

### Mac Development
```bash
python src/main.py
# or
python src/main.py --model world-small
```

### Pi3 Production (Current)
```bash
python src/main.py --profile pi3 --no-display
```

### Pi3 with Speech
```bash
python src/main.py --profile pi3 --no-display --enable-speech
```

### Pi5 Future (8 Motors)
```bash
# After wiring 8 motors and editing config
python src/main.py --profile pi5 --no-display
```

## Configuration Files

### Main Config
[`config/hardware_config.py`](config/hardware_config.py)
- YOLO models
- Motor GPIO pins
- Camera settings
- Detection classes

### Quick Changes

#### Change Model (Pi3)
```python
# config/hardware_config.py
DEFAULT_MODEL = 'nano'  # Current: yolov8n.pt
```

#### Upgrade to 8 Motors
```python
# config/hardware_config.py
MOTOR_PINS = MOTOR_PINS_8  # Change from MOTOR_PINS_2
```

#### Adjust Motor Strength
```python
# config/hardware_config.py
HAPTIC_CONFIG = {
    'default_strength': 0.7,  # 0.0 - 1.0
    'default_duration': 0.3,  # seconds
}
```

## Hardware Setup

### Current (Pi3)
- **Button:** GPIO 5 → GND
- **Left Motor:** GPIO 22 → Driver → Motor
- **Right Motor:** GPIO 26 → Driver → Motor
- **Camera:** Raspberry Pi Camera Module

### Future (Pi5 - 8 Motors)
Additional motors on GPIO: 17, 18, 23, 24, 25, 27

## Testing

### Check if hardware works
```bash
# Button
python -c "from hardware.button_interface import ButtonInterface; b = ButtonInterface(); print('Button:', b._is_pi)"

# Motors
python -c "from hardware.haptic_controller import HapticController; h = HapticController(); h.trigger_vibration({'left': 0.5})"

# Camera
python -c "from perception.camera import CameraInterface; c = CameraInterface(); print('Camera started:', c.start()); c.stop()"
```

## Troubleshooting

### Model not found
```bash
# Download model
cd perception
wget https://github.com/ultralytics/assets/releases/download/v8.1.0/yolov8n.pt
```

### Motors not working
- Check wiring (GPIO 22, 26)
- Verify gpiozero installed: `pip install gpiozero`
- Test with `python -c "from gpiozero import PWMOutputDevice; m = PWMOutputDevice(22); m.value = 0.5; import time; time.sleep(1); m.off()"`

### Camera not working
- Pi: `sudo apt install python3-picamera2`
- Check camera enabled: `vcgencmd get_camera`

### Import errors
```bash
cd perception
pip install -r requirements.txt
```

## File Structure
```
perception/
├── config/hardware_config.py    ⭐ Main config
├── src/
│   ├── main.py                  ⭐ Run this
│   ├── hardware/                # Hardware interfaces
│   └── perception/              # Detection & camera
├── MODEL_CONFIG.md              📖 Detailed guide
└── requirements.txt             📦 Dependencies
```

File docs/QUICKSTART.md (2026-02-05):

# Quick Start Guide

## Installation

### 1. Create Virtual Environment

```bash
python3 -m venv venv

source venv/bin/activate
```

### 2. Install Dependencies

```bash
pip install -r requirements.txt
```

## Running on Mac (Development/Testing)

**Mac Local Demo:** Tests camera + YOLO detection (without speech workflow)

```bash
source venv/bin/activate  # Mac/Linux

python demo/demo_local.py
```

- Continuously detects objects
- Guides to closest object
- Haptic feedback simulated in console
- Press **'q'** to quit

## Running on Raspberry Pi

**Full Workflow:** Button → Speech → Detection → Haptic Guidance

1. **Connect hardware:**
   - Camera module to CSI port
   - Button to GPIO 5 (and GND)
   - Left motor to GPIO 22
   - Right motor to GPIO 26

2. **Run the demo:**
```bash
python demo/demo.py
```

**Workflow:**
1. Press button → System listens for 3 seconds
2. Say object name (e.g., "bottle", "cup", "phone")
3. Camera detects only that object
4. Motors vibrate to indicate direction (left/right/both)

**Alternative - using main.py directly:**
```bash
cd perception
python src/main.py --profile pi3 --no-display --enable-speech
```

## Command Line Options

```bash
python src/main.py --help
```

- `--model`: Path to YOLO-World model (default: yolov8s-world.pt)
- `--no-display`: Disable visual display (for production on RPi)
- `--motors`: Number of haptic motors (default: 8)

## Testing

Run unit tests:
```bash
pytest test/
```

## How It Works

**Workflow Pipeline:**

1. **Button Press** → User presses button to activate
2. **Speech-to-Text (STT)** → User says target object name (e.g., "bottle", "cup", "phone")
3. **YOLO Detection** → Camera detects ONLY that specific object
4. **Haptic Guidance** → Motors vibrate based on object direction:
   - Object on left → Left motor vibrates
   - Object on right → Right motor vibrates  
   - Object centered → Both motors vibrate
   - No object found → System keeps searching

**Technical Flow:**
1. **Camera** captures live video feed
2. **YOLO-World** detects the specified target object (open-vocabulary)
3. **Directional guidance** based on object position in frame
4. **Haptic feedback** provides directional cues:
   - 2 motors (left/right) for Pi3
   - 8 motors (circular array) for Pi5
   - Console simulation on Mac

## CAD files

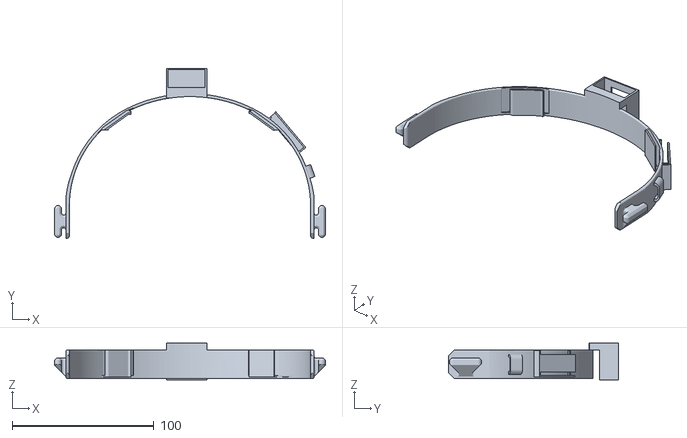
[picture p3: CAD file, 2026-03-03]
CAD/Fusion360/main_part_v2.stl
191.0 x 119.8 x 26.0

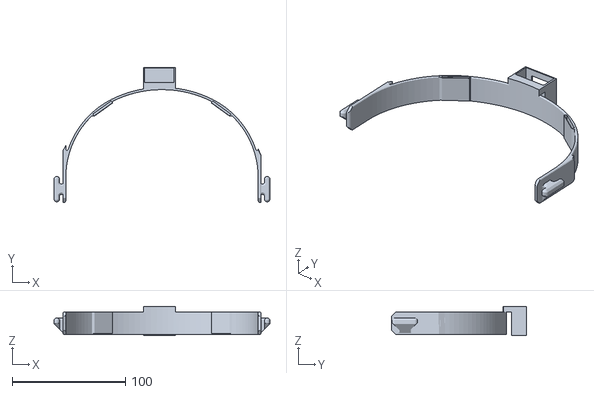
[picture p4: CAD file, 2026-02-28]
CAD/Fusion360/main part new 27.02.stl
191.0 x 119.8 x 26.0

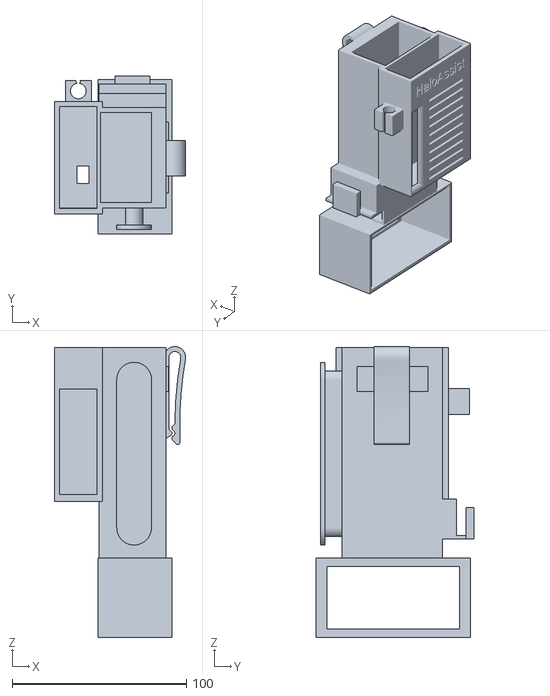
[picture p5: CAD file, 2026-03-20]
CAD/Fusion360/HaloClip_thick_current.stl
75.5 x 90.5 x 167.2

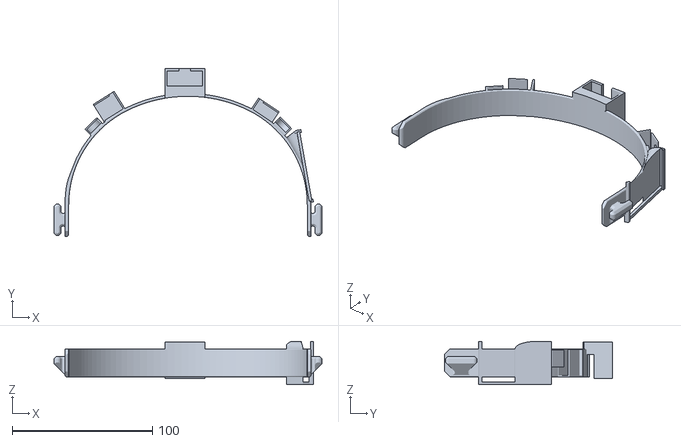
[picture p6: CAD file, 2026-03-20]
CAD/Fusion360/headband front v3.stl
191.0 x 119.9 x 31.0

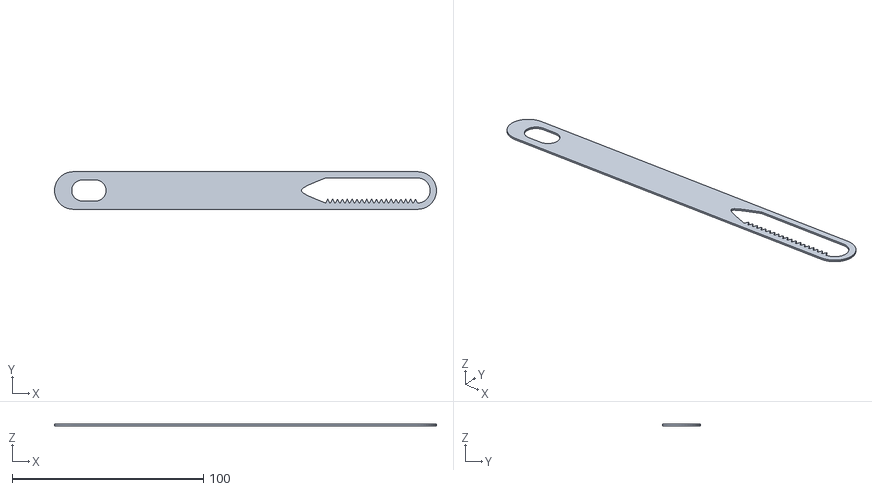
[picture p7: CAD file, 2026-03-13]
CAD/Fusion360/longer__band.stl
199.9 x 19.7 x 0.8

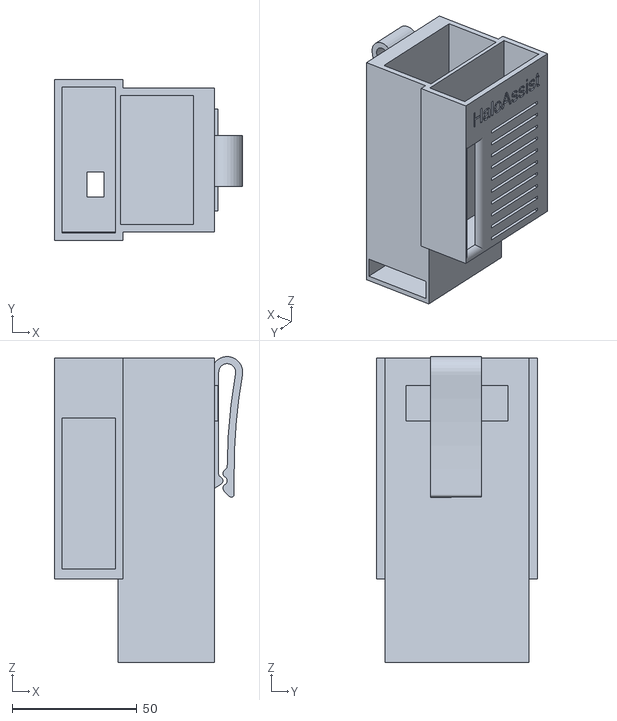
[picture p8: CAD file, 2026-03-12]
CAD/Fusion360/HaloClip_thick_12_03.stl
75.5 x 64.6 x 122.6

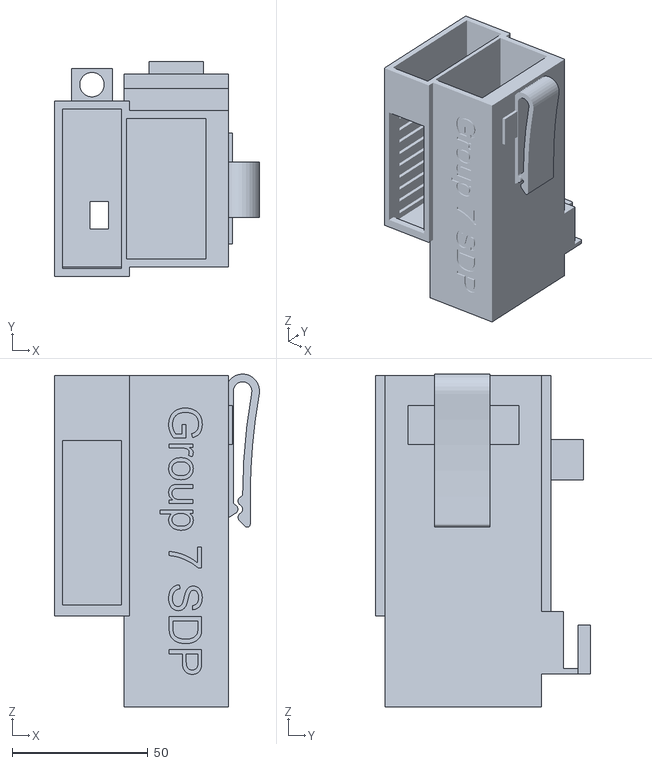
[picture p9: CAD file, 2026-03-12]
CAD/Fusion360/HaloClip_thick_12_03_v2.stl
75.5 x 79.1 x 122.6

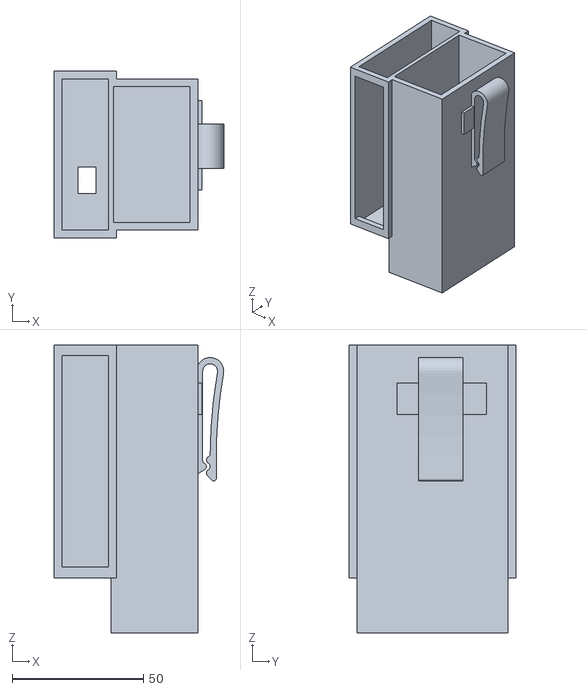
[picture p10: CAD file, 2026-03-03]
CAD/Fusion360/HaloClip_thick.stl
64.5 x 63.6 x 109.6

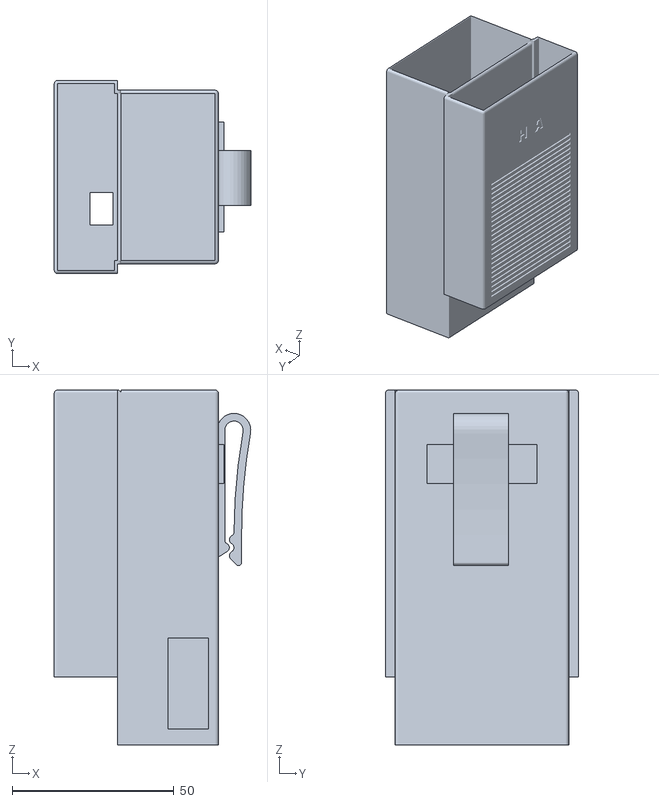
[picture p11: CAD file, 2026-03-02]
CAD/Fusion360/HaloClip.stl
60.7 x 59.6 x 109.6

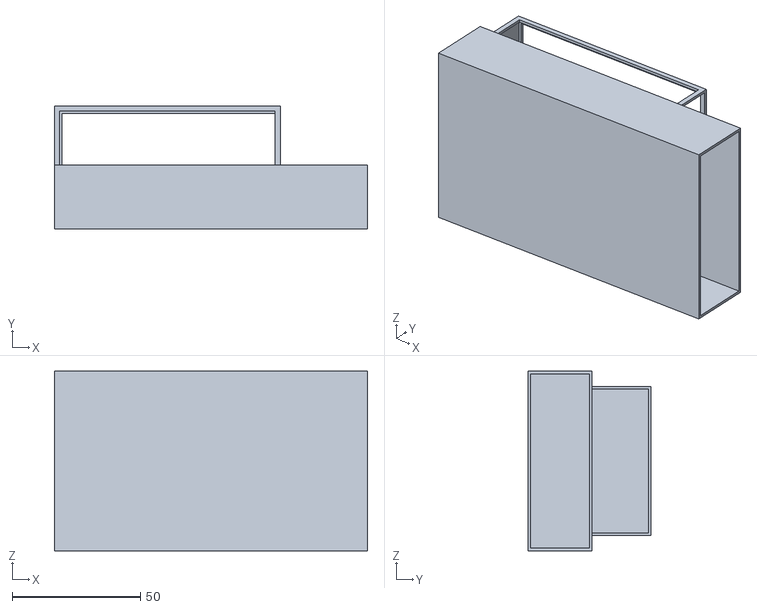
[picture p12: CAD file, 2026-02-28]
CAD/Fusion360/Simple Pi3B+ and powerbank box.stl
122.0 x 48.0 x 70.0

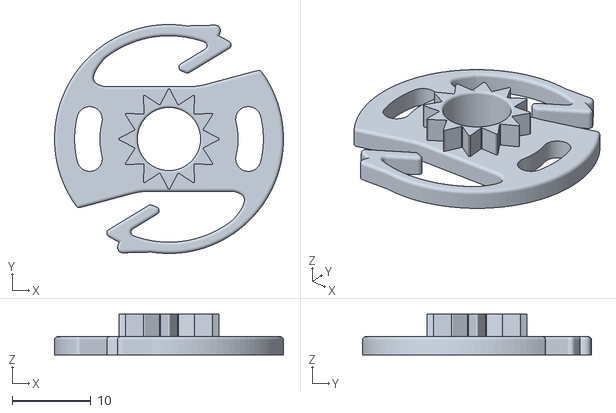
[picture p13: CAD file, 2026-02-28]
CAD/Fusion360/internal_gear.stl
29.0 x 29.0 x 5.15

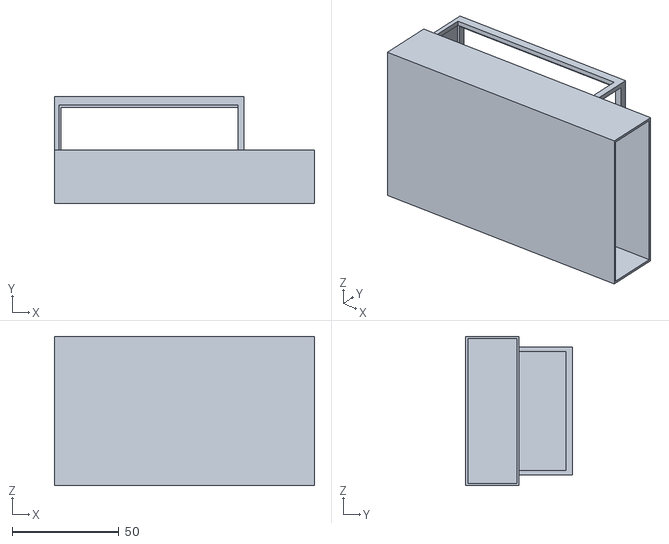
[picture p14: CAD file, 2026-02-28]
CAD/Fusion360/Simple Pi3B+ and powerbank box updated.stl
122.0 x 50.0 x 70.0

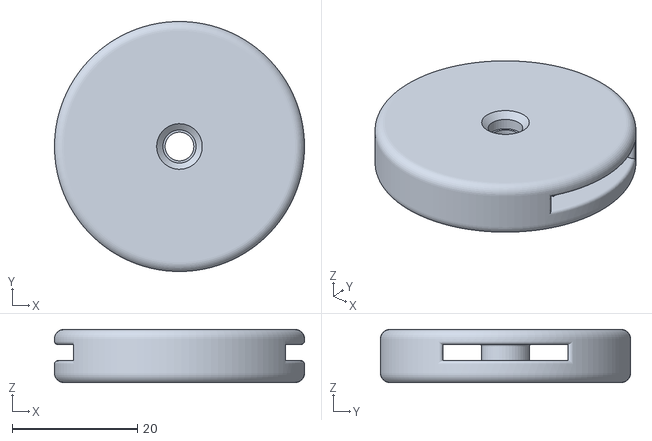
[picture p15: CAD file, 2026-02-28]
CAD/Fusion360/part_1.stl
40.0 x 40.0 x 8.50

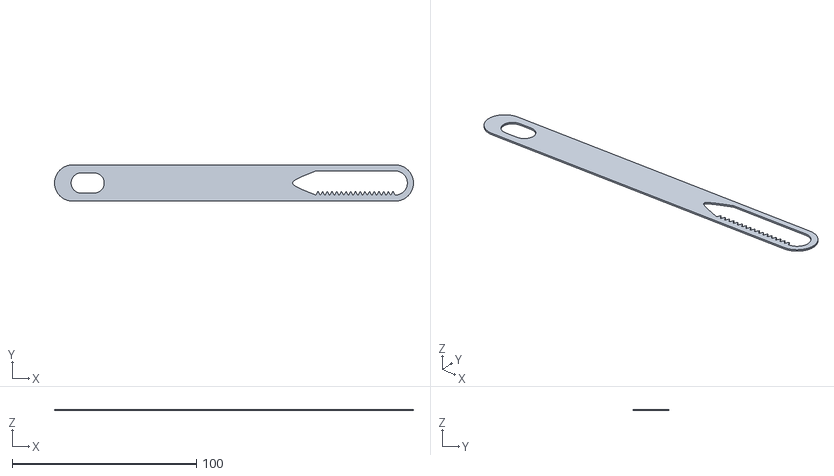
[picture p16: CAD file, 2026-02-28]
CAD/Fusion360/band.stl
194.9 x 19.7 x 0.8

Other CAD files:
CAD/Fusion360/part_2.stl
CAD/Fusion360/HaloClip_thick_current.f3d
CAD/Fusion360/band.f3d
CAD/Fusion360/internal_gear.f3d
CAD/Fusion360/part_1.f3d
CAD/Fusion360/part_2.f3d

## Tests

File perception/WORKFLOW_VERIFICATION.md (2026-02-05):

# Workflow Verification

## ✅ Verified Pipeline

The perception system now implements the correct workflow:

### Step-by-Step Flow

```
1. 🔘 Button Press
   └─> User presses button on GPIO 5
       (Simulated on Mac for testing)

2. 🎤 Speech-to-Text (STT)
   └─> System listens for 3 seconds
   └─> User says target object: "bottle", "cup", "phone", etc.
   └─> Text is recognized via Vosk
   └─> Target object stored in system

3. 🎯 YOLO Detection Update
   └─> For YOLO-World: Updates detection classes to [target_object]
   └─> For standard YOLO: Filters results for target object
   └─> Camera continuously captures frames
   └─> Detects ONLY the specified object

4. 📍 Direction Analysis
   └─> If object detected:
       ├─> Calculate object center position
       ├─> Compare to frame center
       └─> Determine direction: left/center/right

5. 📳 Haptic Feedback
   └─> Based on object position:
       ├─> Left third → Left motor vibrates (GPIO 22)
       ├─> Right third → Right motor vibrates (GPIO 26)
       └─> Center third → Both motors vibrate

6. 🔄 Continuous Loop
   └─> System keeps detecting and guiding
   └─> Press button again to change target object
```

## Code Verification

### 1. Button Press Detection ✅
**Location:** [perception/src/main.py](perception/src/main.py) line ~115

```python
if self.button.is_pressed():
    print("🔘 Button pressed!")
```

### 2. Speech-to-Text ✅
**Location:** [perception/src/main.py](perception/src/main.py) line ~117-125

```python
if self.speech and self.speech.is_available():
    print("🎤 Listening for target object...")
    text = self.speech.listen(duration=3)
    if text and text.strip():
        self.target_object = text.strip().lower()
        print(f"✅ Target set: '{self.target_object}'")
```

### 3. YOLO Detection Update ✅
**Location:** [perception/src/main.py](perception/src/main.py) line ~126-132

```python
# Update YOLO-World detection classes
if self.is_yolo_world:
    self.detector.model.set_classes([self.target_object])
    print(f"🎯 YOLO-World now detecting: {self.target_object}")
```

### 4. Target-Specific Detection ✅
**Location:** [perception/src/main.py](perception/src/main.py) line ~138-147

```python
if self.target_object:
    detections = self.detector.detect(frame)
    
    # Filter for target object
    target = None
    for det in detections:
        if self.target_object in det['class'].lower():
            target = det
            break
```

### 5. Directional Haptic Feedback ✅
**Location:** 
- [perception/src/main.py](perception/src/main.py) line ~150-157 (calls guide_to_target)
- [perception/src/hardware/haptic_controller.py](perception/src/hardware/haptic_controller.py) line ~110-125

```python
# In main.py:
if target is not None:
    self.haptic.guide_to_target(
        target['center'], 
        (frame.shape[1] // 2, frame.shape[0] // 2),
        frame.shape[1]
    )

# In haptic_controller.py:
if x_center < frame_width / 3:
    self.trigger_vibration({'left': strength, 'right': 0.0})  # LEFT
elif x_center > 2 * frame_width / 3:
    self.trigger_vibration({'left': 0.0, 'right': strength})  # RIGHT
else:
    self.trigger_vibration({'left': strength, 'right': strength})  # CENTER
```

## Testing the Workflow

### On Mac (Development)

```bash
cd perception
python demo/demo.py
```

**Expected behavior:**
1. Camera window opens
2. Console shows: "⏸️  Waiting for button press to set target object..."
3. Press any key (button simulation on Mac)
4. System prompts for speech input (may not work on Mac without Vosk)
5. Type or simulate: "bottle"
6. Console shows: "✅ Target set: 'bottle'"
7. Console shows: "🎯 YOLO-World now detecting: bottle"
8. Camera detects bottles only
9. When bottle detected:
   - Console: "🎯 Found: bottle at (x, y) (conf: 0.xx)"
   - Console: "[HAPTIC] {'left': 50} for 0.25s" (or 'right', or both)

### On Raspberry Pi (Production)

```bash
cd perception
python src/main.py --profile pi3 --no-display --enable-speech
```

**Expected behavior:**
1. System initializes
2. Console: "⚠️  WORKFLOW: Press button and say the object you want to find"
3. User presses physical button (GPIO 5)
4. Console: "🔘 Button pressed!"
5. Console: "🎤 Listening for target object..."
6. User says: "bottle"
7. Console: "✅ Target set: 'bottle'"
8. Console: "🎯 YOLO-World now detecting: bottle"
9. Camera starts detecting bottles
10. When bottle found:
    - Console: "🎯 Found: bottle at (x, y)"
    - Left motor vibrates (if bottle on left)
    - Right motor vibrates (if bottle on right)
    - Both motors vibrate (if bottle centered)

## Verification Checklist

- [x] Button press triggers STT
- [x] STT captures target object name
- [x] YOLO-World updates to detect only target object
- [x] Detection filters for target object
- [x] Haptic feedback based on object direction:
  - [x] Left → Left motor
  - [x] Right → Right motor
  - [x] Center → Both motors
- [x] System searches continuously until object found
- [x] Can change target by pressing button again

## Models Supported

### ✅ YOLO-World (Recommended)
- **Models:** yolov8s-world.pt, yolov8m-world.pt
- **Advantage:** Can detect ANY object by name
- **How it works:** `model.set_classes([target_object])` updates classes dynamically
- **Use case:** Perfect for this workflow - detects whatever user says

### ⚠️ Standard YOLO
- **Models:** yolov8n.pt, yolov8s.pt, yolov8m.pt
- **Limitation:** Only detects 80 pre-trained COCO classes
- **How it works:** Filters detections for target object name
- **Use case:** Faster but limited to known classes

**Recommendation:** Use YOLO-World models (`--model world-small`) for full flexibility.

## Quick Commands

### Test on Mac
```bash
python demo/demo.py
```

### Run on Pi3 (Current)
```bash
python src/main.py --profile pi3 --no-display --enable-speech
```

### Run on Pi5 (Future)
```bash
python src/main.py --profile pi5 --no-display --enable-speech
```

## Summary

✅ **Workflow verified:** Button → STT → YOLO Detection → Directional Haptic  
✅ **Speech input working:** Captures target object name  
✅ **YOLO-World integration:** Updates classes based on speech  
✅ **Haptic direction:** Left/Right/Center based on object position  
✅ **Continuous search:** System keeps looking until object found  
✅ **Ready for testing:** Code implements complete pipeline

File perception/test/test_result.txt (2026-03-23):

================================================================================
END-TO-END LATENCY TEST SUITE
================================================================================
Testing system responsiveness for real-time blind assistance
================================================================================

Press ENTER to test camera frame latency...

================================================================================
TEST 1: Camera Frame Capture Latency
================================================================================
Testing: Time to capture a single frame from camera
================================================================================

[0:10:07.538140031] [4919]  INFO Camera camera_manager.cpp:330 libcamera v0.5.2+99-bfd68f78
[0:10:07.545176079] [4926]  INFO RPI pisp.cpp:720 libpisp version v1.2.1 981977ff21f3 29-04-2025 (14:13:50)
[0:10:07.547648744] [4926]  INFO IPAProxy ipa_proxy.cpp:180 Using tuning file /usr/share/libcamera/ipa/rpi/pisp/imx219.json
[0:10:07.554717171] [4926]  INFO Camera camera_manager.cpp:220 Adding camera '/base/axi/pcie@1000120000/rp1/i2c@88000/imx219@10' for pipeline handler rpi/pisp
[0:10:07.554775784] [4926]  INFO RPI pisp.cpp:1179 Registered camera /base/axi/pcie@1000120000/rp1/i2c@88000/imx219@10 to CFE device /dev/media0 and ISP device /dev/media2 using PiSP variant BCM2712_D0
[0:10:07.558327808] [4919]  INFO Camera camera.cpp:1215 configuring streams: (0) 1280x720-XBGR8888/sRGB (1) 1920x1080-BGGR_PISP_COMP1/RAW
[0:10:07.558477136] [4926]  INFO RPI pisp.cpp:1483 Sensor: /base/axi/pcie@1000120000/rp1/i2c@88000/imx219@10 - Selected sensor format: 1920x1080-SBGGR10_1X10/RAW - Selected CFE format: 1920x1080-PC1B/RAW
PiCamera2 started: 1280x720
Camera initialized. Capturing frames...
Sample     Latency (ms)    Status    
----------------------------------------
1              3.98       ✓
2              6.73       ✓
3             65.82       ✓
4             65.71       ✓
5             66.40       ✓
11            66.75       ✓
21            67.08       ✓

================================================================================
📊 STATISTICS FOR REPORT:
================================================================================

Metric               Value       
-----------------------------------
Samples              30          
Mean                 62.79       ms
Median               66.85       ms
Std Dev              15.63       ms
Min                  3.98        ms
Max                  67.82       ms
95th percentile      67.79       ms
99th percentile      67.82       ms

Frame rate           15.9        FPS

--------------------------------------------------------------------------------
Assessment: ✅ GOOD - Acceptable for real-time detection

================================================================================
📋 COPY THIS TO YOUR REPORT:
================================================================================
Camera Frame Capture Latency:
  Mean: 62.79ms (±15.63ms)
  Range: 3.98ms - 67.82ms
  Frame Rate: 15.9 FPS
================================================================================

Press ENTER to test object detection latency...

================================================================================
TEST 2: Object Detection Latency (YOLO Inference)
================================================================================
Testing: Time for YOLO model to process one frame
================================================================================

Loading YOLO model...
WARNING ⚠️ Download failure, retrying 1/3 https://github.com/ultralytics/assets/releases/download/v8.4.0/yolov8n.pt... <urlopen error [SSL: CERTIFICATE_VERIFY_FAILED] certificate verify failed: Hostname mismatch, certificate is not valid for 'github.com'. (_ssl.c:992)>
curl: (60) SSL: no alternative certificate subject name matches target host name 'github.com'
More details here: https://curl.se/docs/sslcerts.html

curl failed to verify the legitimacy of the server and therefore could not
establish a secure connection to it. To learn more about this situation and
how to fix it, please visit the web page mentioned above.

WARNING ⚠️ Download failure, retrying 2/3 https://github.com/ultralytics/assets/releases/download/v8.4.0/yolov8n.pt... Curl return value 60
curl: (60) SSL: no alternative certificate subject name matches target host name 'github.com'
More details here: https://curl.se/docs/sslcerts.html

curl failed to verify the legitimacy of the server and therefore could not
establish a secure connection to it. To learn more about this situation and
how to fix it, please visit the web page mentioned above.

WARNING ⚠️ Download failure, retrying 3/3 https://github.com/ultralytics/assets/releases/download/v8.4.0/yolov8n.pt... Curl return value 60
curl: (60) SSL: no alternative certificate subject name matches target host name 'github.com'
More details here: https://curl.se/docs/sslcerts.html

curl failed to verify the legitimacy of the server and therefore could not
establish a secure connection to it. To learn more about this situation and
how to fix it, please visit the web page mentioned above.

❌ Error: ❌  Download failure for https://github.com/ultralytics/assets/releases/download/v8.4.0/yolov8n.pt. Retry limit reached. Curl return value 60
Traceback (most recent call last):
  File "/home/ubuntu/HaloAssistV2/.venv/lib/python3.11/site-packages/ultralytics/utils/downloads.py", line 331, in safe_download
    assert r == 0, f"Curl return value {r}"
           ^^^^^^
AssertionError: Curl return value 60

The above exception was the direct cause of the following exception:

Traceback (most recent call last):
  File "/home/ubuntu/SDP-project-Haloassist/perception/test/test_end_to_end_latency.py", line 156, in test_detection_latency
    detector = ObjectDetector(model_path='yolov8n.pt')  # Use nano for speed
               ^^^^^^^^^^^^^^^^^^^^^^^^^^^^^^^^^^^^^^^
  File "/home/ubuntu/SDP-project-Haloassist/perception/test/../src/perception/detector.py", line 50, in __init__
    self.model = YOLO(model_path)
                 ^^^^^^^^^^^^^^^^
  File "/home/ubuntu/HaloAssistV2/.venv/lib/python3.11/site-packages/ultralytics/models/yolo/model.py", line 76, in __init__
    super().__init__(model=model, task=task, verbose=verbose)
  File "/home/ubuntu/HaloAssistV2/.venv/lib/python3.11/site-packages/ultralytics/engine/model.py", line 144, in __init__
    self._load(model, task=task)
  File "/home/ubuntu/HaloAssistV2/.venv/lib/python3.11/site-packages/ultralytics/engine/model.py", line 283, in _load
    self.model, self.ckpt = load_checkpoint(weights)
                            ^^^^^^^^^^^^^^^^^^^^^^^^
  File "/home/ubuntu/HaloAssistV2/.venv/lib/python3.11/site-packages/ultralytics/nn/tasks.py", line 1507, in load_checkpoint
    ckpt, weight = torch_safe_load(weight)  # load ckpt
                   ^^^^^^^^^^^^^^^^^^^^^^^
  File "/home/ubuntu/HaloAssistV2/.venv/lib/python3.11/site-packages/ultralytics/nn/tasks.py", line 1433, in torch_safe_load
    file = attempt_download_asset(weight)  # search online if missing locally
           ^^^^^^^^^^^^^^^^^^^^^^^^^^^^^^
  File "/home/ubuntu/HaloAssistV2/.venv/lib/python3.11/site-packages/ultralytics/utils/downloads.py", line 469, in attempt_download_asset
    safe_download(url=f"{download_url}/{release}/{name}", file=file, min_bytes=1e5, **kwargs)
  File "/home/ubuntu/HaloAssistV2/.venv/lib/python3.11/site-packages/ultralytics/utils/downloads.py", line 372, in safe_download
    raise ConnectionError(emojis(f"❌  Download failure for {uri}. Retry limit reached. {e}")) from e
ConnectionError: ❌  Download failure for https://github.com/ultralytics/assets/releases/download/v8.4.0/yolov8n.pt. Retry limit reached. Curl return value 60
Press ENTER to test haptic response latency...

================================================================================
TEST 3: Haptic Feedback Response Latency
================================================================================
Testing: Time to trigger motor response
Note: Non-blocking implementation should be < 5ms
================================================================================

⚠️ Haptic motors simulated (hardware IO disabled)
Sample     guide_to_target (ms)      update_motors (ms)  
------------------------------------------------------------
1                 0.010                   0.004
2                 0.004                   0.001
3                 0.003                   0.001
4                 0.003                   0.001
5                 0.003                   0.001
6                 0.003                   0.001
11                0.002                   0.001
16                0.002                   0.001
Haptic motors cleaned up

================================================================================
📊 STATISTICS FOR REPORT:
================================================================================

--- guide_to_target() ---

Metric               Value       
-----------------------------------
Samples              20          
Mean                 0.00        ms
Median               0.00        ms
Std Dev              0.00        ms
Min                  0.00        ms
Max                  0.01        ms
95th percentile      0.01        ms
99th percentile      0.01        ms

--- update_motors() ---

Metric               Value       
-----------------------------------
Samples              20          
Mean                 0.00        ms
Median               0.00        ms
Std Dev              0.00        ms
Min                  0.00        ms
Max                  0.00        ms
95th percentile      0.00        ms
99th percentile      0.00        ms

--- Total Haptic Latency ---

Metric               Value       
-----------------------------------
Samples              20          
Mean                 0.00        ms
Median               0.00        ms
Std Dev              0.00        ms
Min                  0.00        ms
Max                  0.01        ms
95th percentile      0.01        ms
99th percentile      0.01        ms

--------------------------------------------------------------------------------
Assessment: ✅ EXCELLENT - Non-blocking implementation working perfectly

================================================================================
📋 COPY THIS TO YOUR REPORT:
================================================================================
Haptic Feedback Latency:
  guide_to_target(): 0.003ms (±0.002ms)
  update_motors(): 0.001ms (±0.001ms)
  Total: 0.004ms (±0.003ms)
  → Non-blocking design achieved <5ms latency ✅
================================================================================

Press ENTER to test continuous loop (30s)...

================================================================================
TEST 4: Continuous Detection Loop (30s)
================================================================================
Testing: Frame-to-feedback latency during real operation
Simulates actual usage scenario
================================================================================

WARNING ⚠️ Download failure, retrying 1/3 https://github.com/ultralytics/assets/releases/download/v8.4.0/yolov8n.pt... <urlopen error [SSL: CERTIFICATE_VERIFY_FAILED] certificate verify failed: Hostname mismatch, certificate is not valid for 'github.com'. (_ssl.c:992)>
curl: (60) SSL: no alternative certificate subject name matches target host name 'github.com'
More details here: https://curl.se/docs/sslcerts.html

curl failed to verify the legitimacy of the server and therefore could not
establish a secure connection to it. To learn more about this situation and
how to fix it, please visit the web page mentioned above.

WARNING ⚠️ Download failure, retrying 2/3 https://github.com/ultralytics/assets/releases/download/v8.4.0/yolov8n.pt... Curl return value 60
curl: (60) SSL: no alternative certificate subject name matches target host name 'github.com'
More details here: https://curl.se/docs/sslcerts.html

curl failed to verify the legitimacy of the server and therefore could not
establish a secure connection to it. To learn more about this situation and
how to fix it, please visit the web page mentioned above.

WARNING ⚠️ Download failure, retrying 3/3 https://github.com/ultralytics/assets/releases/download/v8.4.0/yolov8n.pt... Curl return value 60
curl: (60) SSL: no alternative certificate subject name matches target host name 'github.com'
More details here: https://curl.se/docs/sslcerts.html

curl failed to verify the legitimacy of the server and therefore could not
establish a secure connection to it. To learn more about this situation and
how to fix it, please visit the web page mentioned above.

❌ Error: ❌  Download failure for https://github.com/ultralytics/assets/releases/download/v8.4.0/yolov8n.pt. Retry limit reached. Curl return value 60
Traceback (most recent call last):
  File "/home/ubuntu/HaloAssistV2/.venv/lib/python3.11/site-packages/ultralytics/utils/downloads.py", line 331, in safe_download
    assert r == 0, f"Curl return value {r}"
           ^^^^^^
AssertionError: Curl return value 60

The above exception was the direct cause of the following exception:

Traceback (most recent call last):
  File "/home/ubuntu/SDP-project-Haloassist/perception/test/test_end_to_end_latency.py", line 358, in test_continuous_loop_latency
    detector = ObjectDetector(model_path='yolov8n.pt')
               ^^^^^^^^^^^^^^^^^^^^^^^^^^^^^^^^^^^^^^^
  File "/home/ubuntu/SDP-project-Haloassist/perception/test/../src/perception/detector.py", line 50, in __init__
    self.model = YOLO(model_path)
                 ^^^^^^^^^^^^^^^^
  File "/home/ubuntu/HaloAssistV2/.venv/lib/python3.11/site-packages/ultralytics/models/yolo/model.py", line 76, in __init__
    super().__init__(model=model, task=task, verbose=verbose)
  File "/home/ubuntu/HaloAssistV2/.venv/lib/python3.11/site-packages/ultralytics/engine/model.py", line 144, in __init__
    self._load(model, task=task)
  File "/home/ubuntu/HaloAssistV2/.venv/lib/python3.11/site-packages/ultralytics/engine/model.py", line 283, in _load
    self.model, self.ckpt = load_checkpoint(weights)
                            ^^^^^^^^^^^^^^^^^^^^^^^^
  File "/home/ubuntu/HaloAssistV2/.venv/lib/python3.11/site-packages/ultralytics/nn/tasks.py", line 1507, in load_checkpoint
    ckpt, weight = torch_safe_load(weight)  # load ckpt
                   ^^^^^^^^^^^^^^^^^^^^^^^
  File "/home/ubuntu/HaloAssistV2/.venv/lib/python3.11/site-packages/ultralytics/nn/tasks.py", line 1433, in torch_safe_load
    file = attempt_download_asset(weight)  # search online if missing locally
           ^^^^^^^^^^^^^^^^^^^^^^^^^^^^^^
  File "/home/ubuntu/HaloAssistV2/.venv/lib/python3.11/site-packages/ultralytics/utils/downloads.py", line 469, in attempt_download_asset
    safe_download(url=f"{download_url}/{release}/{name}", file=file, min_bytes=1e5, **kwargs)
  File "/home/ubuntu/HaloAssistV2/.venv/lib/python3.11/site-packages/ultralytics/utils/downloads.py", line 372, in safe_download
    raise ConnectionError(emojis(f"❌  Download failure for {uri}. Retry limit reached. {e}")) from e
ConnectionError: ❌  Download failure for https://github.com/ultralytics/assets/releases/download/v8.4.0/yolov8n.pt. Retry limit reached. Curl return value 60

================================================================================
================================================================================
📊 FINAL SUMMARY - COMPLETE REPORT DATA
================================================================================
================================================================================

================================================================================
TABLE 1: Component-Level Latency
================================================================================
Component                 Mean (ms)    Std Dev      95th %ile   
--------------------------------------------------------------------------------
Camera Frame Capture         62.79       15.63       67.79
Haptic Feedback              0.004       0.003       0.013
================================================================================

================================================================================
KEY FINDINGS FOR REPORT:
================================================================================

3. OPTIMIZATION SUCCESS:
   • Haptic feedback latency: 0.004ms
   • ✅ Non-blocking design achieved <5ms target
   • Minimal overhead compared to total loop time

4. CAMERA PERFORMANCE:
   • Frame capture: 62.79ms
   • Capable of 15.9 FPS

================================================================================
OPTIMIZATIONS IMPLEMENTED:
================================================================================
  ✓ Non-blocking haptic pulses (eliminated time.sleep)
  ✓ Button-held STT (variable duration, no fixed 3s wait)
  ✓ Removed unnecessary delays in main loop
  ✓ Efficient I2C communication for haptic drivers

================================================================================
RECOMMENDATIONS FOR FURTHER OPTIMIZATION (if needed):
================================================================================

================================================================================
OVERALL ASSESSMENT:
================================================================================

================================================================================
 LATENCY TESTING COMPLETE!

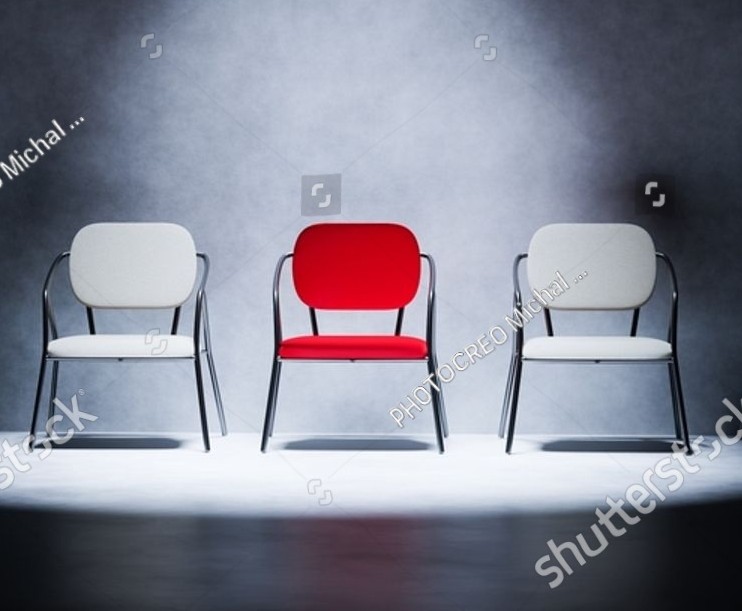
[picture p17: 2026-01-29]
perception/test_images/chair.jpg

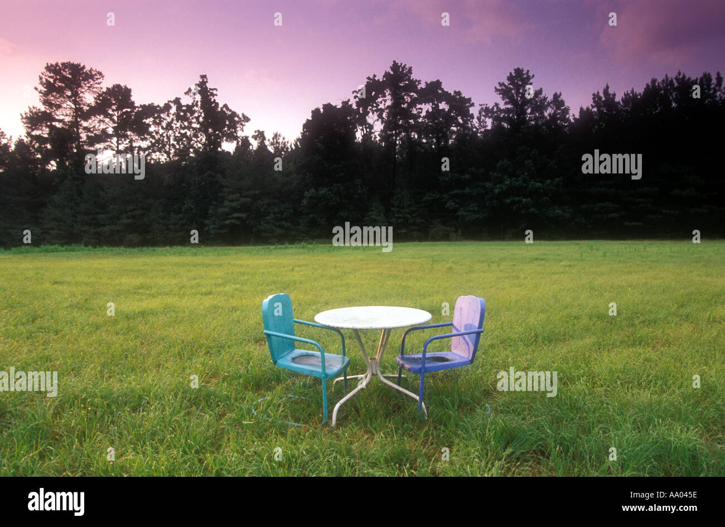
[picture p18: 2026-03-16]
perception/test_images/chair_far.jpg

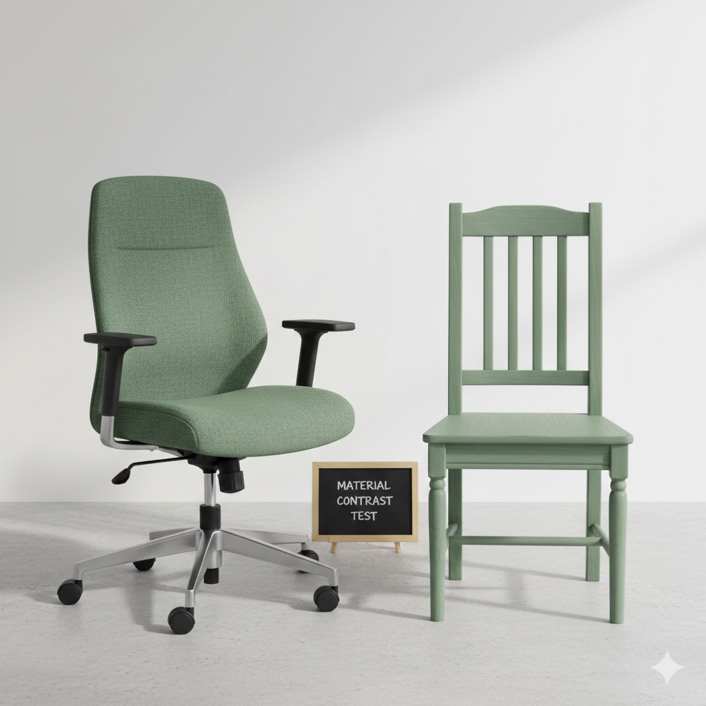
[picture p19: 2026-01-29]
perception/test_images/chair3.jpg

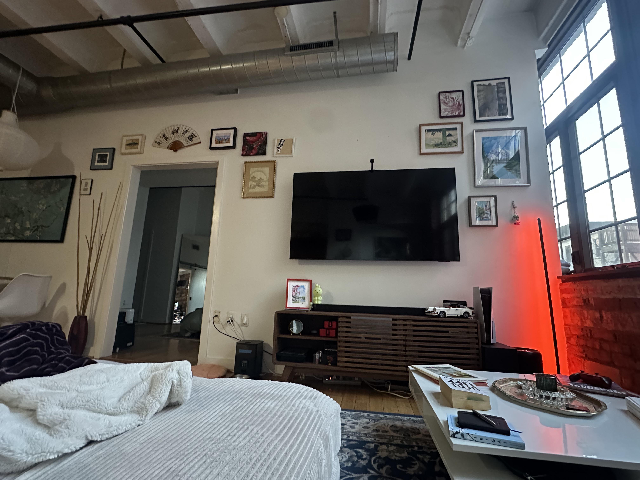
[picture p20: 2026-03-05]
test_images/test12.jpeg

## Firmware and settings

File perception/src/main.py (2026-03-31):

"""
Main application entry point.
Integrates target-object detection, haptic guidance, speech input, and feedback services.
"""
from typing import Optional
import argparse
import datetime
import os
import socket
import subprocess
import sys
import time
from pathlib import Path

try:
    import cv2
except ImportError:
    cv2 = None

# Ensure local modules are importable when running this file directly.
project_root = Path(__file__).parent.parent
sys.path.insert(0, str(project_root))
sys.path.insert(0, str(project_root / "config"))
sys.path.insert(0, str(project_root.parent / "visualization"))
sys.path.insert(0, str(project_root.parent))

from perception.detector import detect_target_object
from perception_config import (
    COCO_CLASSES,
    CONFIDENCE_DECAY_PER_MISS,
    CONFIDENCE_SUCCESS_MARGIN,
    CONFIDENCE_THRESHOLD,
    MIN_CONFIDENCE_THRESHOLD,
    YOLOE_CONFIDENCE_DISCOUNT,
    YOLO_MODELS,
)
from run_config import RUN_CONFIG

KEY_ESCAPE = 27


class PerceptionSystem:
    def __init__(self):
        self.model_paths = YOLO_MODELS
        self.active_model_key = "yoloe-26-seg"
        self.active_model_path = self.model_paths[self.active_model_key]
        self.visualizer_server_process = None
        self._get_extracted_object = None
        HapticController = None
        ButtonInterface = None
        CameraInterface = None
        STTInterface = None
        TTSInterface = None
        AudioFeedback = None
        HapticVisualizer = None

        if RUN_CONFIG["enable_haptic"]:
            try:
                from hardware.haptic_controller import HapticController
            except Exception as exc:
                print(f"⚠️  Haptic module unavailable: {exc}")
        if RUN_CONFIG["enable_button"]:
            try:
                from hardware.button_interface import ButtonInterface
            except Exception as exc:
                print(f"⚠️  Button module unavailable: {exc}")
        if RUN_CONFIG["enable_camera"]:
            try:
                from hardware.camera_interface import CameraInterface
            except Exception as exc:
                print(f"⚠️  Camera module unavailable: {exc}")
        if RUN_CONFIG["enable_speech"]:
            try:
                from services.stt_interface import STTInterface
            except Exception as exc:
                print(f"⚠️  STT module unavailable: {exc}")
        if RUN_CONFIG["enable_tts"]:
            try:
                from services.tts_interface import TTSInterface
            except Exception as exc:
                print(f"⚠️  TTS module unavailable: {exc}")
        if RUN_CONFIG["enable_audio"]:
            try:
                from services.audio_feedback import AudioFeedback
            except Exception as exc:
                print(f"⚠️  Audio module unavailable: {exc}")
        if RUN_CONFIG["enable_visualizer"]:
            try:
                from visualization.haptic_client import HapticVisualizer
            except Exception as exc:
                print(f"⚠️  Visualizer client unavailable: {exc}")

        if RUN_CONFIG["enable_visualizer"]:
            self._ensure_visualizer_server()

        def _safe_init(factory, name: str):
            if factory is None:
                return None
            try:
                return factory()
            except Exception as exc:
                print(f"⚠️  {name} init failed: {exc}")
                return None

        self.haptic = _safe_init(HapticController, "Haptic")
        # Button is only required when speech interaction is enabled.
        self.button = _safe_init(ButtonInterface, "Button") if RUN_CONFIG["enable_speech"] else None
        self.stt = _safe_init(STTInterface, "STT")
        self.tts = _safe_init(TTSInterface, "TTS")
        self.audio = _safe_init(AudioFeedback, "Audio feedback")
        self.camera = _safe_init(lambda: CameraInterface(width=1280, height=720), "Camera")
        self.visualizer = _safe_init(HapticVisualizer, "Visualizer")

        self.show_display = RUN_CONFIG["show_display"] and cv2 is not None
        if RUN_CONFIG["show_display"] and cv2 is None:
            print("⚠️  OpenCV not installed; disabling display window.")
        self.target_object: Optional[str] = None
        self.is_idle = True
        self.detected_objects = []
        self.matched_target_obj = None
        self.current_conf_threshold = CONFIDENCE_THRESHOLD

        if self.visualizer:
            self.visualizer.searching(self.target_object or "")

        if RUN_CONFIG["enable_speech"]:
            try:
                from llm.extractor import get_extracted_object, load_extractor_model
                configured_model = Path(str(RUN_CONFIG.get("llm_extractor_model", "gemma3-vosk-q4.gguf"))).expanduser()
                if not configured_model.is_absolute():
                    configured_model = project_root.parent / configured_model
                gguf_path = Path(
                    os.environ.get(
                        "HALOASSIST_GGUF_MODEL",
                        str(configured_model),
                    )
                )
                if gguf_path.exists():
                    self._get_extracted_object = get_extracted_object
                    load_extractor_model(str(gguf_path))
                else:
                    print(f"⚠️  LLM model not found at {gguf_path}")
                    print("   Speech target extraction will fallback to raw speech text.")
            except Exception as exc:
                print(f"⚠️  LLM extractor unavailable: {exc}")
                print("   Speech target extraction will fallback to raw speech text.")

        print("Perception System initialized")
        print(f"  YOLO model:     auto-select ({self.active_model_key})")
        print(f"  Base conf:      {CONFIDENCE_THRESHOLD:.2f}")
        print(f"  Haptic:         {'enabled' if self.haptic else 'DISABLED'}")
        print(f"  Button:         {'enabled' if self.button else 'DISABLED'}")
        print(f"  Speech (STT):   {'enabled' if self.stt and self.stt.is_available() else 'DISABLED'}")
        print(f"  TTS:            {'enabled' if self.tts and self.tts.is_available() else 'DISABLED'}")
        print(f"  Audio feedback: {'enabled' if self.audio else 'DISABLED'}")
        print(f"  Visualizer:     {'enabled' if self.visualizer else 'DISABLED'}")
        if self.visualizer:
            print(f"  Visualizer URL: {self.visualizer.base_url}")
        print(f"  Display:        {'enabled' if self.show_display else 'DISABLED'}")

    def _is_tcp_port_open(self, host: str, port: int) -> bool:
        try:
            with socket.create_connection((host, port), timeout=0.3):
                return True
        except OSError:
            return False

    def _ensure_visualizer_server(self):
        host = "127.0.0.1"
        port = 8000

        if self._is_tcp_port_open(host, port):
            return

        server_script = project_root.parent / "visualization" / "server.py"
        if not server_script.exists():
            print(f"⚠️  Visualizer server script not found: {server_script}")
            return

        print("Starting visualizer server on http://localhost:8000 ...")
        try:
            self.visualizer_server_process = subprocess.Popen(
                [sys.executable, str(server_script)],
                cwd=str(server_script.parent),
                stdout=subprocess.PIPE,
                stderr=subprocess.PIPE,
                text=True,
            )
        except Exception as exc:
            print(f"⚠️  Failed to start visualizer server: {exc}")
            return

        deadline = time.time() + 5.0
        while time.time() < deadline:
            if self._is_tcp_port_open(host, port):
                print("Visualizer server is ready.")
                return
            if self.visualizer_server_process.poll() is not None:
                stdout_text, stderr_text = self.visualizer_server_process.communicate(timeout=1)
                if stderr_text.strip():
                    print("⚠️  Visualizer server failed to start. stderr:")
                    print(stderr_text.strip())
                elif stdout_text.strip():
                    print("⚠️  Visualizer server exited early. stdout:")
                    print(stdout_text.strip())
                break
            time.sleep(0.2)

        print("⚠️  Visualizer server did not become ready in time.")

    def _target_in_coco(self, target_object: str) -> bool:
        return target_object.lower() in COCO_CLASSES

    def _select_model_for_target(self):
        if not self.target_object:
            self.active_model_key = "yoloe-26-seg"
        else:
            self.active_model_key = "yolo26n" if self._target_in_coco(self.target_object) else "yoloe-26-seg"
        self.active_model_path = self.model_paths[self.active_model_key]

    def _get_model_adjusted_threshold(self) -> float:
        threshold = self.current_conf_threshold
        if self.active_model_key == "yoloe-26-seg":
            threshold -= YOLOE_CONFIDENCE_DISCOUNT
        return max(MIN_CONFIDENCE_THRESHOLD, threshold)

    def _on_detection_miss(self):
        self.current_conf_threshold = max(
            MIN_CONFIDENCE_THRESHOLD,
            self.current_conf_threshold - CONFIDENCE_DECAY_PER_MISS,
        )

    def _on_detection_success(self, detected_confidence: float):
        self.current_conf_threshold = max(
            MIN_CONFIDENCE_THRESHOLD,
            detected_confidence - CONFIDENCE_SUCCESS_MARGIN,
        )

    def _listen_and_set_target(self):
        if not (self.stt and self.stt.is_available()):
            return

        if not self.button:
            print("Button interface unavailable. Cannot trigger speech listening.")
            return

        if self.audio:
            self.audio.button_press()

        text = self.stt.listen_while_pressed(self.button.is_pressed)
        if not text or not text.strip():
            print("No speech recognised. Keeping current target.")
            if self.tts:
                self.tts.speak("I did not hear anything.")
            if self.audio:
                self.audio.error()
            return

        if self._get_extracted_object is not None:
            extraction = self._get_extracted_object(text)
            valid = (
                extraction.status == "success"
                and extraction.object_of_interest.strip().lower() not in ("n/a", "large yellow pickaxe")
            )

            if valid:
                self.target_object = extraction.object_of_interest.strip().lower()
            else:
                print("LLM extraction failed; using raw speech text as fallback target.")
                self.target_object = text.strip().lower()
        else:
            self.target_object = text.strip().lower()

        self._select_model_for_target()
        self.current_conf_threshold = CONFIDENCE_THRESHOLD
        print(f"Target changed to: '{self.target_object}'")
        print(f"Using model: {self.active_model_key}")

        if self.visualizer:
            self.visualizer.searching(self.target_object or "")
        if self.tts:
            self.tts.speak("Looking for " + self.target_object)
        if self.audio:
            self.audio.success()

        self.is_idle = False

    def _handle_button(self):
        if not (self.button and self.button.is_pressed()):
            return

        if self.is_idle:
            print("\nButton pressed. Listening while held...")
            self._listen_and_set_target()
        else:
            self.target_object = None
            self._select_model_for_target()
            self.is_idle = True
            self.detected_objects = []
            self.matched_target_obj = None
            self.current_conf_threshold = CONFIDENCE_THRESHOLD
            print("Search stopped.")
            if self.tts:
                self.tts.speak("Search stopped")
            if self.visualizer:
                self.visualizer.stop()
            if self.audio:
                self.audio.button_release()

    def _run_detection(self, frame):
        if not self.target_object:
            self.detected_objects = []
            self.matched_target_obj = None
            return

        self._select_model_for_target()
        detection = detect_target_object(
            frame=frame,
            min_conf=self._get_model_adjusted_threshold(),
            target_obj=self.target_object,
            model_path=self.active_model_path,
        )

        if detection is None:
            self.detected_objects = []
            self.matched_target_obj = None
            self._on_detection_miss()
            return

        self._on_detection_success(detection.confidence)
        x1, y1, x2, y2 = [int(v) for v in detection.bbox]
        cx, cy = [int(v) for v in detection.center]
        self.matched_target_obj = {
            "class": self.target_object,
            "bbox": [x1, y1, x2, y2],
            "center": (cx, cy),
            "confidence": detection.confidence,
        }
        self.detected_objects = [self.matched_target_obj]

    def _update_visualizer(self, matched_target: Optional[dict], frame):
        if not self.visualizer:
            return

        if matched_target:
            if self.haptic and hasattr(self.haptic, "_left_intensity") and hasattr(self.haptic, "_right_intensity"):
                intensity_left = max(0.0, min(1.0, float(getattr(self.haptic, "_left_intensity", 0.0))))
                intensity_right = max(0.0, min(1.0, float(getattr(self.haptic, "_right_intensity", 0.0))))
                # Determine direction from which motor is dominant.
                # Both motors are always slightly on (support ratio), so we
                # must compare intensities rather than just checking > 0.
                left_on = intensity_left > 0.0
                right_on = intensity_right > 0.0
                if not left_on and not right_on:
                    position = None
                elif abs(intensity_left - intensity_right) <= 0.05:
                    position = "center"
                elif intensity_left > intensity_right:
                    position = "left"
                else:
                    position = "right"
            else:
                offset = (matched_target["center"][0] - frame.shape[1] / 2) / (frame.shape[1] / 2)
                position = "left" if offset < -0.33 else ("right" if offset > 0.33 else "center")
                intensity_left = abs(offset) if offset < 0 else 0.0
                intensity_right = abs(offset) if offset > 0 else 0.0
                left_on = offset < 0
                right_on = offset > 0

            self.visualizer.update_motors(
                left=left_on,
                right=right_on,
                intensity_left=intensity_left,
                intensity_right=intensity_right,
                target_object=self.target_object,
                position=position,
            )
        else:
            self.visualizer.searching(self.target_object or "")

    def _log_status(self, matched_target):
        current_time = datetime.datetime.now()
        if not hasattr(self, "_last_log_time"):
            self._last_log_time = current_time
        if (current_time - self._last_log_time).total_seconds() < 1:
            return

        self._last_log_time = current_time
        timestamp = current_time.strftime("%Y-%m-%d %H:%M:%S")
        if matched_target:
            print(
                f"[{timestamp}] Found: {matched_target['class']} at {matched_target['center']} "
                f"(conf: {matched_target['confidence']:.2f}, min: {self._get_model_adjusted_threshold():.2f})"
            )
        elif self.target_object:
            print(
                f"[{timestamp}] Searching for '{self.target_object}' "
                f"(min: {self._get_model_adjusted_threshold():.2f})..."
            )
        else:
            print(f"[{timestamp}] Idle (no target set)")

    def _update_visual_display(self, frame, detections: list, matched_target, frame_count: int, fps_start: float) -> bool:
        if not self.show_display or frame is None or cv2 is None:
            return True

        display = frame.copy()
        for det in detections:
            x1, y1, x2, y2 = det["bbox"]
            is_target = det == matched_target
            color = (0, 255, 0) if is_target else (255, 0, 0)
            thickness = 3 if is_target else 1

            cv2.rectangle(display, (x1, y1), (x2, y2), color, thickness)
            cv2.putText(
                display,
                f"{det['class']} {det['confidence']:.2f}",
                (x1, y1 - 10),
                cv2.FONT_HERSHEY_SIMPLEX,
                0.5,
                color,
                2,
            )

            if is_target:
                cx, cy = det["center"]
                cv2.circle(display, (cx, cy), 8, (0, 0, 255), -1)
                cv2.putText(display, "TARGET", (cx - 30, cy - 15), cv2.FONT_HERSHEY_SIMPLEX, 0.6, (0, 0, 255), 2)

        if RUN_CONFIG["fps_display"]:
            fps = frame_count / max(1e-6, (time.time() - fps_start))
            cv2.putText(display, f"FPS: {fps:.1f}", (10, 30), cv2.FONT_HERSHEY_SIMPLEX, 1, (0, 255, 0), 2)

        cv2.imshow("Perception System", display)
        return cv2.waitKey(1) & 0xFF != KEY_ESCAPE

    def _cleanup(self):
        print("Cleaning up...")
        if self.audio:
            self.audio.shutdown()
        if self.camera:
            self.camera.stop()
        if self.haptic:
            self.haptic.cleanup()
        if self.button:
            self.button.cleanup()
        if self.tts:
            self.tts.cleanup()
        if self.visualizer:
            self.visualizer.stop()
        if self.visualizer_server_process and self.visualizer_server_process.poll() is None:
            self.visualizer_server_process.terminate()
            try:
                self.visualizer_server_process.wait(timeout=2)
            except Exception:
                self.visualizer_server_process.kill()
        if self.show_display:
            cv2.destroyAllWindows()
        print("System stopped.")

    def run(self):
        print("\nStarting perception system...")
        if self.camera and not self.camera.start():
            print("Failed to start camera. Continuing without camera.")
            self.camera = None

        if self.audio:
            self.audio.bootup()

        frame_count = 0
        fps_start = time.time()

        try:
            while True:
                self._handle_button()
                camera_frame = self.camera.read_frame() if self.camera else None
                
                if self.camera and camera_frame is None:
                    print("Warning: failed to read frame from camera")
                    continue

                self._run_detection(camera_frame)
                
                if self.haptic:
                    self.haptic.calc_motor_strengths(
                        self.matched_target_obj["center"] if self.matched_target_obj else None,
                        (camera_frame.shape[1] // 2, camera_frame.shape[0] // 2),
                        camera_frame.shape[1],
                    )
                    self.haptic.update_motors()

                self._update_visualizer(self.matched_target_obj, camera_frame)

                frame_count += 1
                self._log_status(self.matched_target_obj)
                if not self._update_visual_display(camera_frame, self.detected_objects, 
                                                   self.matched_target_obj, frame_count, fps_start):
                    break

        except KeyboardInterrupt:
            print("\nKeyboard interrupt received. Stopping...")
        finally:
            self._cleanup()
            time.sleep(1)

def main():
    parser = argparse.ArgumentParser(description="HaloAssist Perception System")
    parser.add_argument("--disable-haptics", action="store_true", help="Disable haptic feedback")
    parser.add_argument("--disable-speech", action="store_true", help="Disable speech input")
    parser.add_argument("--disable-tts", action="store_true", help="Disable text-to-speech output")
    parser.add_argument("--disable-audio", action="store_true", help="Disable audio feedback")
    parser.add_argument("--disable-visualizer", action="store_true", help="Disable visualizer")
    args = parser.parse_args()

    if args.disable_haptics:
        RUN_CONFIG["enable_haptic"] = False
    if args.disable_speech:
        RUN_CONFIG["enable_speech"] = False
    if args.disable_tts:
        RUN_CONFIG["enable_tts"] = False
    if args.disable_audio:
        RUN_CONFIG["enable_audio"] = False
    if args.disable_visualizer:
        RUN_CONFIG["enable_visualizer"] = False

    PerceptionSystem().run()


if __name__ == "__main__":
    main()

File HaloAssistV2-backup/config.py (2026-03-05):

# config.py

PULSE_INTERVAL = 0.5
PULSE_DURATION = 0.05

CAMERA_INDEX = 0
FRAME_WIDTH = 640
FRAME_HEIGHT = 480
FPS = 30

MODEL_PATH = "yoloe-26n-seg.pt"
CLASSES = ["cone", "bottle"]

IMG_SIZE = 256
CONF_THRESHOLD = 0.1

LEFT_PIN = 22
RIGHT_PIN = 26
BUTTON_PIN = 5

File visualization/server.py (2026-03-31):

#!/usr/bin/env python3
"""
FastAPI server for motor vibration visualization
Receives motor status updates and broadcasts to web clients via WebSocket
"""
import asyncio
from fastapi import FastAPI, WebSocket, WebSocketDisconnect
from fastapi.staticfiles import StaticFiles
from fastapi.responses import FileResponse
from pydantic import BaseModel
from typing import List, Optional
import json
from datetime import datetime
from pathlib import Path

app = FastAPI(title="Motor Vibration Visualizer")

BASE_DIR = Path(__file__).resolve().parent
STATIC_DIR = BASE_DIR / "static"

# Store connected WebSocket clients
connected_clients: List[WebSocket] = []

# Current motor state
motor_state = {
    "left": False,
    "right": False,
    "intensity_left": 0.0,
    "intensity_right": 0.0,
    "target_object": None,
    "position": None,  # "left", "right", "center"
    "last_update": None
}


class MotorUpdate(BaseModel):
    """Motor status update from the perception system"""
    left: bool = False
    right: bool = False
    intensity_left: float = 1.0
    intensity_right: float = 1.0
    target_object: Optional[str] = None
    position: Optional[str] = None


class DetectionUpdate(BaseModel):
    """Detection info from the perception system"""
    target_object: str
    position: str  # "left", "right", "center"
    confidence: float = 0.0


async def broadcast_state():
    """Broadcast current motor state to all connected clients"""
    if connected_clients:
        message = json.dumps({
            "type": "motor_state",
            "data": motor_state
        })
        disconnected = []
        for client in connected_clients:
            try:
                await client.send_text(message)
            except:
                disconnected.append(client)
        
        # Remove disconnected clients
        for client in disconnected:
            connected_clients.remove(client)


@app.get("/")
async def root():
    """Serve the main visualization page"""
    return FileResponse(STATIC_DIR / "index.html")


@app.post("/api/motor/update")
async def update_motor(update: MotorUpdate):
    """
    Update motor state - called by the perception system
    
    Example:
        POST /api/motor/update
        {"left": true, "right": false, "target_object": "bottle", "position": "left"}
    """
    global motor_state
    
    motor_state["left"] = update.left
    motor_state["right"] = update.right
    motor_state["intensity_left"] = update.intensity_left
    motor_state["intensity_right"] = update.intensity_right
    motor_state["target_object"] = update.target_object
    motor_state["position"] = update.position
    motor_state["last_update"] = datetime.now().isoformat()
    
    await broadcast_state()
    
    return {"status": "ok", "state": motor_state}


@app.post("/api/motor/left/{state}")
async def set_left_motor(state: bool, intensity: float = 1.0):
    """Quick endpoint to toggle left motor"""
    motor_state["left"] = state
    motor_state["intensity_left"] = intensity if state else 0.0
    motor_state["last_update"] = datetime.now().isoformat()
    await broadcast_state()
    return {"status": "ok", "left": state}


@app.post("/api/motor/right/{state}")
async def set_right_motor(state: bool, intensity: float = 1.0):
    """Quick endpoint to toggle right motor"""
    motor_state["right"] = state
    motor_state["intensity_right"] = intensity if state else 0.0
    motor_state["last_update"] = datetime.now().isoformat()
    await broadcast_state()
    return {"status": "ok", "right": state}


@app.post("/api/motor/both/{state}")
async def set_both_motors(state: bool, intensity: float = 1.0):
    """Toggle both motors (center detection)"""
    motor_state["left"] = state
    motor_state["right"] = state
    motor_state["intensity_left"] = intensity if state else 0.0
    motor_state["intensity_right"] = intensity if state else 0.0
    motor_state["position"] = "center" if state else None
    motor_state["last_update"] = datetime.now().isoformat()
    await broadcast_state()
    return {"status": "ok", "both": state}


@app.post("/api/detection")
async def detection_update(detection: DetectionUpdate):
    """
    Receive detection update and trigger appropriate motors
    
    Example:
        POST /api/detection
        {"target_object": "bottle", "position": "left", "confidence": 0.85}
    """
    motor_state["target_object"] = detection.target_object
    motor_state["position"] = detection.position
    motor_state["last_update"] = datetime.now().isoformat()
    
    # Set motors based on position
    if detection.position == "left":
        motor_state["left"] = True
        motor_state["right"] = False
        motor_state["intensity_left"] = min(detection.confidence + 0.3, 1.0)
        motor_state["intensity_right"] = 0.0
    elif detection.position == "right":
        motor_state["left"] = False
        motor_state["right"] = True
        motor_state["intensity_left"] = 0.0
        motor_state["intensity_right"] = min(detection.confidence + 0.3, 1.0)
    elif detection.position == "center":
        motor_state["left"] = True
        motor_state["right"] = True
        intensity = min(detection.confidence + 0.3, 1.0)
        motor_state["intensity_left"] = intensity
        motor_state["intensity_right"] = intensity
    
    await broadcast_state()
    return {"status": "ok", "state": motor_state}


@app.get("/api/motor/state")
async def get_motor_state():
    """Get current motor state"""
    return motor_state


@app.post("/api/motor/stop")
async def stop_motors():
    """Stop all motors"""
    motor_state["left"] = False
    motor_state["right"] = False
    motor_state["intensity_left"] = 0.0
    motor_state["intensity_right"] = 0.0
    motor_state["target_object"] = None
    motor_state["position"] = None
    motor_state["last_update"] = datetime.now().isoformat()
    await broadcast_state()
    return {"status": "ok", "message": "All motors stopped"}


@app.websocket("/ws")
async def websocket_endpoint(websocket: WebSocket):
    """WebSocket endpoint for real-time motor state updates"""
    await websocket.accept()
    connected_clients.append(websocket)
    
    # Send current state on connection
    await websocket.send_text(json.dumps({
        "type": "motor_state",
        "data": motor_state
    }))
    
    try:
        while True:
            # Keep connection alive and handle incoming messages
            data = await websocket.receive_text()
            message = json.loads(data)
            
            # Handle ping/pong for connection keep-alive
            if message.get("type") == "ping":
                await websocket.send_text(json.dumps({"type": "pong"}))
    
    except WebSocketDisconnect:
        if websocket in connected_clients:
            connected_clients.remove(websocket)


# Mount static files
app.mount("/static", StaticFiles(directory=str(STATIC_DIR)), name="static")
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

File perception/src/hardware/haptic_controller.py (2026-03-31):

"""
Haptic Controller
Provides directional guidance using vibration motors.
2-motor (left/right) via I2C MUX + DRV2605 haptic drivers.

Uses Real-Time Playback (RTP) mode for continuous variable intensity.
Hardware: TCA9548A I2C multiplexer -> DRV2605 haptic drivers (ERM mode)
"""
from typing import Optional, Tuple
from pathlib import Path
import sys

config_dir = Path(__file__).parent.parent.parent / "config"
sys.path.insert(0, str(config_dir))

from run_config import RUN_CONFIG

# Haptic mapping knobs.
DEFAULT_MAX_INTENSITY = 0.65
CENTER_BAND = 0.22        # ±22% of half-width (~44% of frame) treated as center zone.
CENTER_INTENSITY = 0.25
INTENSITY_GAMMA = 1.8     # Emphasize differences as target moves away from center.
SUPPORT_RATIO = 0.08      # Non-dominant motor stays very weak for sharp L/R distinction.


class HapticController:
    """Controller for continuous variable haptic feedback via I2C MUX + DRV2605."""

    def __init__(self):
        self.drv_left = None
        self.drv_right = None
        self._available = False

        self.max_intensity = float(RUN_CONFIG.get("haptic_max_intensity", DEFAULT_MAX_INTENSITY))
        self.max_intensity = max(0.0, min(1.0, self.max_intensity))

        self._left_intensity = 0.0
        self._right_intensity = 0.0
        self.num_motors = 2

        try:
            import busio
            import board
            from adafruit_tca9548a import TCA9548A
            import adafruit_drv2605

            i2c = busio.I2C(board.SCL, board.SDA)
            mux = TCA9548A(i2c)

            self.drv_left = adafruit_drv2605.DRV2605(mux[6])
            self.drv_right = adafruit_drv2605.DRV2605(mux[7])

            self.drv_left.use_ERM()
            self.drv_right.use_ERM()

            self.drv_left.mode = adafruit_drv2605.MODE_REALTIME
            self.drv_right.mode = adafruit_drv2605.MODE_REALTIME

            self._available = True
            print("✅ Haptic motors initialized via I2C MUX (Real-Time Mode)")
        except Exception as e:
            print(f"⚠️  Haptic motors unavailable: {e}")

    def is_available(self) -> bool:
        return self._available

    def guide_to_target(
        self,
        target_center: Optional[Tuple[int, int]],
        frame_center: Tuple[int, int],
        frame_width: int,
    ):
        """
        Compute continuous left/right intensity mapping based on horizontal position.
        """
        _ = frame_center
        if target_center is None:
            self._left_intensity = 0.0
            self._right_intensity = 0.0
            return

        if frame_width <= 0:
            self._left_intensity = 0.0
            self._right_intensity = 0.0
            return

        frame_center_x = frame_center[0]
        offset = (target_center[0] - frame_center_x) / (frame_width / 2.0)
        offset = max(-1.0, min(1.0, offset))
        magnitude = abs(offset)

        # Include the exact boundary in the center zone to avoid edge flicker.
        if magnitude <= CENTER_BAND:
            self._left_intensity = CENTER_INTENSITY
            self._right_intensity = CENTER_INTENSITY
            return

        dominant = (magnitude ** INTENSITY_GAMMA) * self.max_intensity
        support = dominant * SUPPORT_RATIO

        if offset < 0:
            self._left_intensity = dominant
            self._right_intensity = support
        else:
            self._left_intensity = support
            self._right_intensity = dominant

    def calc_motor_strengths(
        self,
        target_center: Optional[Tuple[int, int]],
        frame_center: Tuple[int, int],
        frame_width: int,
    ):
        """Backward-compatible alias used by main.py."""
        self.guide_to_target(target_center, frame_center, frame_width)
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

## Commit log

2026-01-27 Very basic rumble motor arduino code
2026-02-02 Add comment header for YOLO haptic vibrations
    [yolo_haptic.py]
2026-02-05 Fix object vibration fallback
    [main.py]
2026-02-26 Adding fusion 360 files for most of the headband
    [band.f3d, internal_gear.f3d, part_1.f3d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]
2026-02-26 stl files for printing
    [Simple Pi3B+ and powerbank box.stl, band.stl, internal_gear.stl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]
2026-02-26 updated file
    [Simple Pi3B+ and powerbank box updated.stl]
2026-02-27 Add files via upload
    Adding main part version 1 ( 2 motors and camera )
    [main part new 27.02.stl]
2026-02-28 Integrate latency fixes and TTS from 1-integration branch
    - Remove time.sleep() blocking in haptic controller; use non-blocking pulse system
    - Add smooth gradient motor strengths instead of fixed 3-zone thresholds
    - Add listen_while_button_pressed() for dynamic-duration STT recording
    - Add Speaker (Piper TTS) interface for voice feedback
    - Update hardware_config with pulse and TTS settings
    - Update main loop: non-blocking motors, button-held STT, TTS confirmation
    [haptic_controller.py, hardware_config.py, main.py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]
2026-03-03 button example
2026-03-03 Fix motor triggering
2026-03-11 Rename HaloClip.stl to HaloClip_OLD.stl
    Re changing file name to avoid confusion
    [HaloClip_OLD.stl]
2026-03-11 Adding button killswitch
2026-03-11 fix: button stop code
    [main.py]
2026-03-11 fix: idle var true
    [main.py]
2026-03-11 fix new button GPIO pin pos
    [button_interface.py]
2026-03-11 simplify and fix import
    [button_interface.py]
2026-03-11 reduce model rejections with oneshot in extractor.py, enhance error detection in main.py 3
    [main.py]
2026-03-12 Adding updated holster 12/03
    [HaloClip_thick_12_03.stl]
2026-03-12 Add files via upload
    Better holster 12/03
    [HaloClip_thick_12_03_v2.stl]
2026-03-12 feat: add continuous motor mapping test
2026-03-12 chore: relocate legacy/demo scripts into archive
    - created `archive/` directory
    - moved `HaloAssistV2-backup`, test_yolo.py, testbutton.py, yolo_haptic.py
    out of the project root
    - restored original hardware/yolo_haptic.py when undoing earlier move
    - clarified that these files are reference/legacy material only
    Keeps workspace tidy and separates active code from archived examples.
2026-03-13 refactor: separate hardware and software configurations
    - moved YOLO models, TTS/STT configs, detection settings, and platform profiles from hardware_config.py to settings.py
    - kept hardware-specific configs (GPIO pins, motor mappings, camera settings) in hardware_config.py
    - updated imports in main.py, detector.py, and tts_interface.py to use settings.py
    - improved config file naming and separation of concerns
2026-03-13 Move camera.py from perception/ to hardware/ for consistent hardware abstraction
2026-03-13 Remove camera.py from perception/ — moved to hardware/
2026-03-13 perception.camera to hardware.camera
2026-03-13 rename camera.py to camera_interface.py and update import in main.py
2026-03-13 remove camera.py — renamed to camera_interface.py
2026-03-13 remove speech_interface.py from hardware/ — moved to services/
2026-03-13 remove tts_interface.py from hardware/ — moved to services/
2026-03-13 remove speech_interface.py — renamed to stt_interface.py
2026-03-13 remove dead haptic constants and fix broken motor_pins references in apply_profile()
2026-03-13 remove duplicate camera config from settings.py, point apply_profile() to hardware_config.CAMERA_CONFIG
2026-03-13 add run_config.py, remove SYSTEM_CONFIG from services_config, wire flags into main.py
2026-03-13 fix tts_interface.py: move numpy/sounddevice imports to __init__, remove per-call import overhead
    [tts_interface.py]
2026-03-13 extract _log_status() from run(), remove inline debug prints from main loop
2026-03-13 change quit key from 'q' to Escape, remove 'Press q to quit' print
2026-03-13 graceful haptic init failure: wrap I2C setup in try/except, set self.haptic=None in main.py if unavailable
    [haptic_controller.py, main.py]
2026-03-13 wire detect_interval into _run_detection: throttle YOLO, reuse last detections on skipped frames
    [main.py]
2026-03-13 Adding the longer band
    [longer__band.stl]
2026-03-16 PCB Files
2026-03-17 update motor_tests
2026-03-17 fixed vibration in the middle
    [haptic_controller.py]
2026-03-19 latest holster with wire loop and speaker placement
    [HaloClip_thick_current.f3d]
2026-03-20 make motor vibrating at centre
    [haptic_controller.py]
2026-03-20 add print for motors sim
2026-03-20 made code runnable on laptop without haptics, fixed import issues,
    [haptic_controller.py, main.py, perception_config.py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]
2026-03-20 reduce debug prints
2026-03-21 clean up, made audio feedback working with threading, made button work with keyboard "b".
2026-03-21 fix detector and haptic
    [HaloClip_OLD.stl, HaloClip_thick.stl, HaloClip_thick_12_03.stl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]
2026-03-23 make button working on pi
2026-03-23 Remove print statement in main loop
    Removed unnecessary print statement from the loop.
2026-03-23 improve motor vibration
2026-03-23 fix vis motor sync
    [main.py]
2026-03-24 update motor to vibrate at center
    [haptic_controller.py, main.py, run_config.py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]
2026-03-24 add a var can modify the intensity of motor

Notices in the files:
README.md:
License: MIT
